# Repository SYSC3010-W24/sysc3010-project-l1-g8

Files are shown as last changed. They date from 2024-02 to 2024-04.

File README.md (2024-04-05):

# 🔥 FANS (Fire Alarm Notification System)

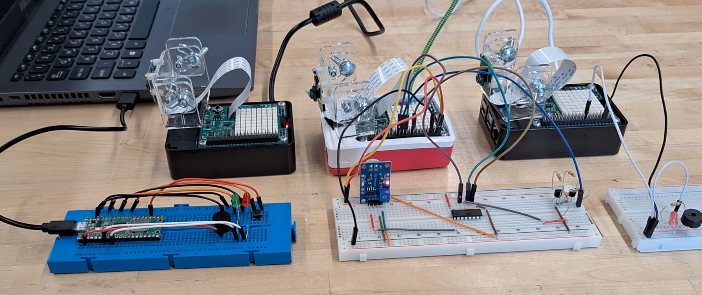
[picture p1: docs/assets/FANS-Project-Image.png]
Project Image


FANS is a comprehensive multi-system solution for fire-related emergencies that require prompt notification of persons
in the affected area.

FANS utilizes smoke and temperature sensors to accurately detect fires in its surrounding environment. Upon detection,
FANS issues SMS and email notifications to individuals in the surrounding area.

FANS provides a dashboard for live monitoring of its environment, as well as an interface for customizing things like
its sensitivity to pressure changes.

## Table Of Contents

- [Contributors](#contributors)  
- [Repository Organization](#repository-organization)
- [Installation and Setup Guide](#installation-and-setup-guide)
  - [Sensor Pi](#sensor-pi)
  - [Alarm System](#alarm-system)
  - [Notifier](#notifier)
  - [Pico Alarm](#pico-alarm)
  - [Web App](#web-app)

## Contributors

SYSC3010 group L1-G8, under guidance of TA Sean Kirkby.

- Grant Achuzia
- Javeria Sohail
- Matteo Golin
- Saja Fawagreh

## Repository Organization

FANS is composed of several different nodes. Within the project repository, each node is given its own directory
containing its required files.

- The data collection system is stored in [`sensor-pi/`][sensor-pi]
- The notification system is stored in [`notifier/`][notifier]
- The web GUI is stored in [`web-app/`][gui]
- The alarm system is stored in [`alarm-system/`][alarm]
- The haptic alarm system is stored in [`pico_alarm/`][haptic]

In addition, the `docs/` directory contains documentation on our system design. Within `docs/`, the `assets/` folder
contains all of the UML class, sequence, state machine and deployment diagrams which describe the FANS system and which
are used throughout our reports. The `design-report/` folder contains all of the LaTeX source files that compose the
FANS design report, and the `proposal/` folder contains the LaTeX source files for building our initial project proposal.

## Installation and Setup Guide

Guides to install and run each system node are provided below. Once all nodes have been set up, the system will be
functional.

- [Sensor Pi](#sensor-pi)
- [Alarm System](#alarm-system)
- [Notifier](#notifier)
- [Pico Alarm](#pico-alarm)
- [Web App](#web-app)

### Sensor-Pi

In order to set up the `sensor-pi` sensor data collection system, you will need:

- Raspberry Pi 4
- Sense hat
- Breadboard
- Wires
- 2x 10k resistors
- 2x 1k resistors
- 2x NPN bipolar-junction transistors
- Flying fish MQ2 smoke detector module

In order to assemble the circuit, place the components on your breadboard according to the following schematic. Power
sources can come from the Raspberry Pi or an external source. The labelled pin outputs (GPIO 22, SCLK, MOSI, MISO) are
all meant to be connected to the corresponding pin on the Raspberry Pi 4. Please see its [pinout][pi-pinout] sheet to
locate this pins.

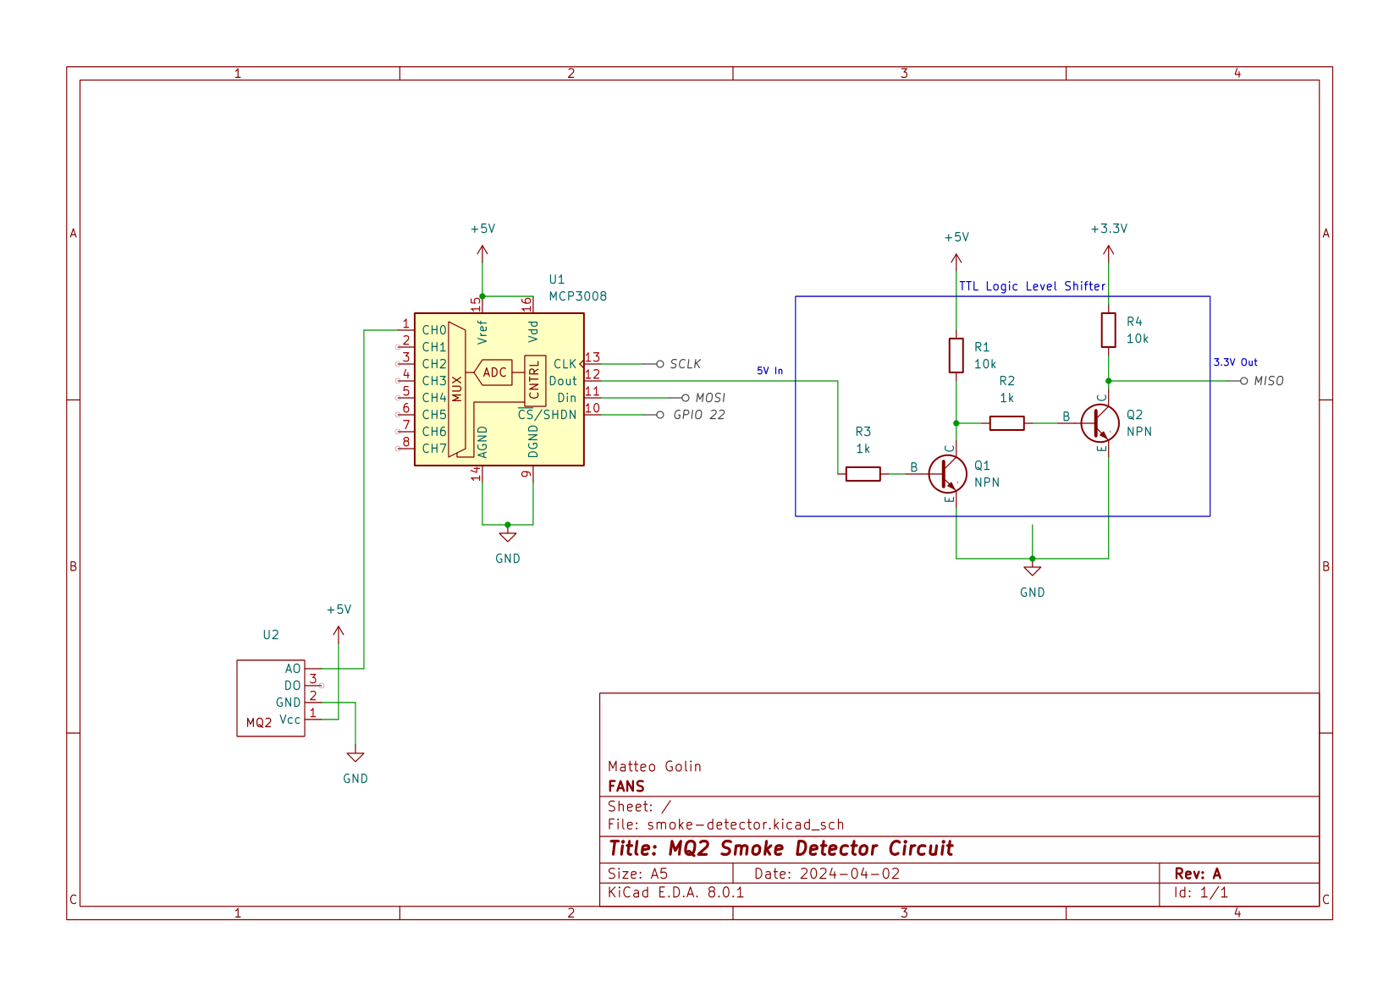
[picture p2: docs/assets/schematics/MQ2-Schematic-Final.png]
MQ2 smokedetector circuit


Ensure that the following files are present in the same directory for it to function properly:

- `firebase_config.json`: This file should include the configuration details required to connect to the Firebase
  database, such as the API key, authentication domain, database URL, and storage bucket.

Example `firebase_config.json` file:

```json
{
  "apiKey": "yourKey",
  "authDomain": "yourDomain",
  "databaseURL": "https://your-database-url",
  "storageBucket": "someStorageBucket"
}
```

Once the circuit is built and connected, the node can be started by running the software located in the `sensor-pi`
directory from the Raspberry Pi. Python 3.11 must be previously installed. The following commands will download the
repository and start the software when run in the terminal:

```console
git clone https://github.com/SYSC3010-W24/sysc3010-project-l1-g8.git
cd sysc-project-l1-g8/sensor-pi
python3 -m venv venv
source venv/bin/activate
pip install -r requirements.txt
python3 main.py
```

### Alarm System

In order to set up the `alarm-system` node, you will need:

- Raspberry Pi 4
- Breadboard
- Wires
- Passive piezoelectric buzzer
- Red LED
- 1k resistor

In order to assemble the circuit, place the components on your breadboard according to the following schematic. The 3.3V
input signal should be connected to the Raspberry Pi's GPIO 22 pin. Please see the Pi's [pinout][pi-pinout] sheet to
connect the pins properly.

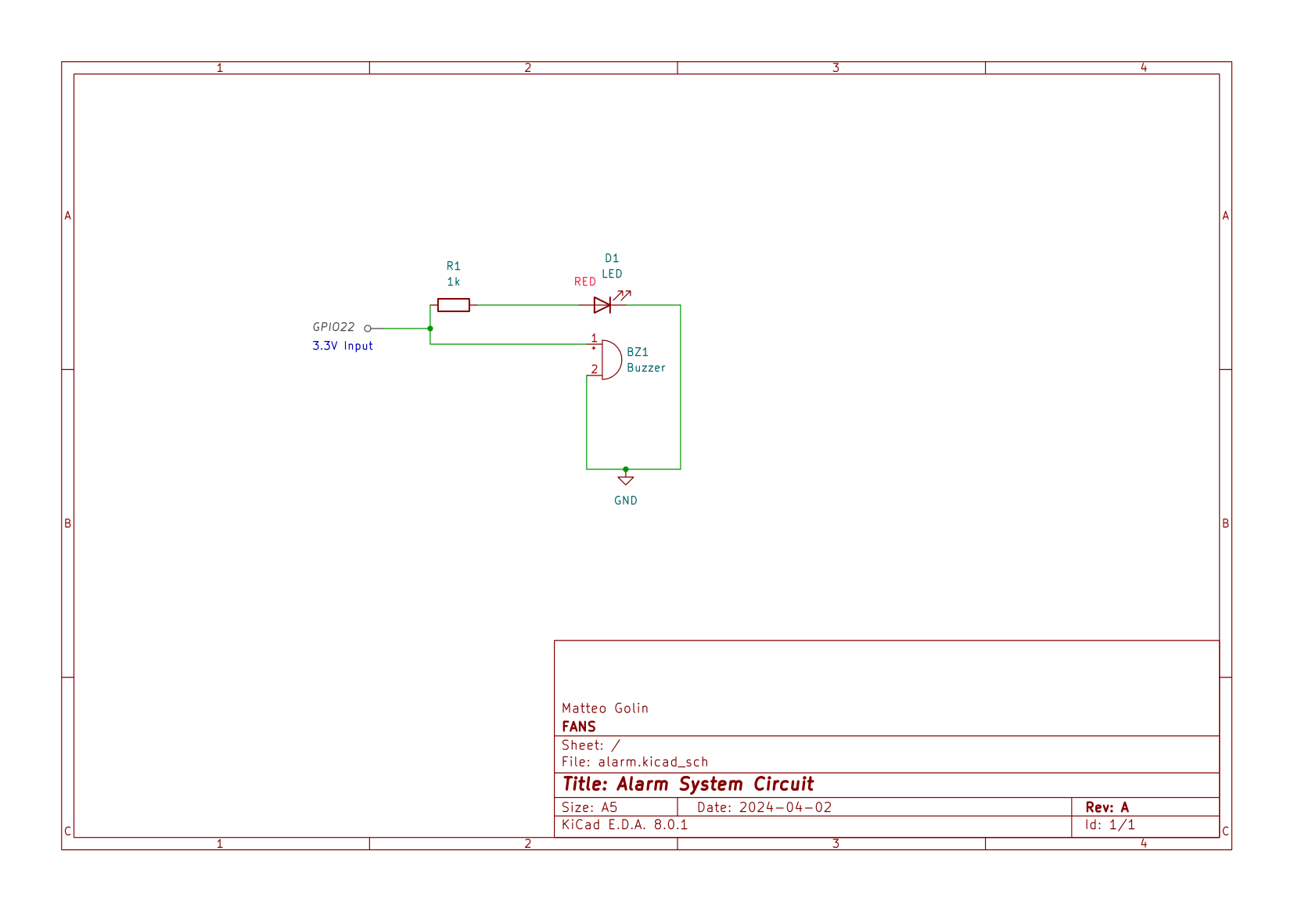
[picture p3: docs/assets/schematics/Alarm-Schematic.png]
Alarm system circuit


Once the circuit is assembled and connected, the node can be started by running the software located in the
`alarm-system` directory from the Raspberry Pi. Python 3.11 must be previously installed. The following commands will
download the repository and start the software when run in the terminal:

```console
git clone https://github.com/SYSC3010-W24/sysc3010-project-l1-g8.git
cd sysc-project-l1-g8/alarm-system
python3 -m venv venv
source venv/bin/activate
pip install -r requirements.txt
python3 main.py
```

### Notifier

In order to set up the `notifier` node, you will need:

- Raspberry Pi 4

The node can be started by running the software located in the notifier directory on the Raspberry Pi. Prior installation of Python 3.11 is required. Execute the following commands in the terminal to download the repository and start the software:

```console
git clone https://github.com/SYSC3010-W24/sysc3010-project-l1-g8.git
cd sysc-project-l1-g8/notifier
python3 -m venv venv
source venv/bin/activate
pip install -r requirements.txt
python3 email_notification_system.py
```

Additionally, ensure that the following files are present in the same directory for it to function properly:

- `fans_credentials.json`: This file should contain the username and password required for authentication to the email server, enabling the system to send notifications via email.
- `firebase_config.json`: This file should include the configuration details required to connect to the Firebase database, such as the API key, authentication domain, database URL, and storage bucket.
- `twilio_credentials.json`: This file should contain the authentication credentials for accessing the Twilio API, including the account SID and authentication token, enabling the system to send notifications via SMS.

### Pico-Alarm

In order to set up the `pico_alarm` buzzer alarm and led notifier system, you will need:

- Raspberry Pi Pico W
- Piezoelectric Buzzer
- 1 red and 1 green LED
- Breadboard
- Wires
- 2x 10k resistors

#### Hardware Assembly

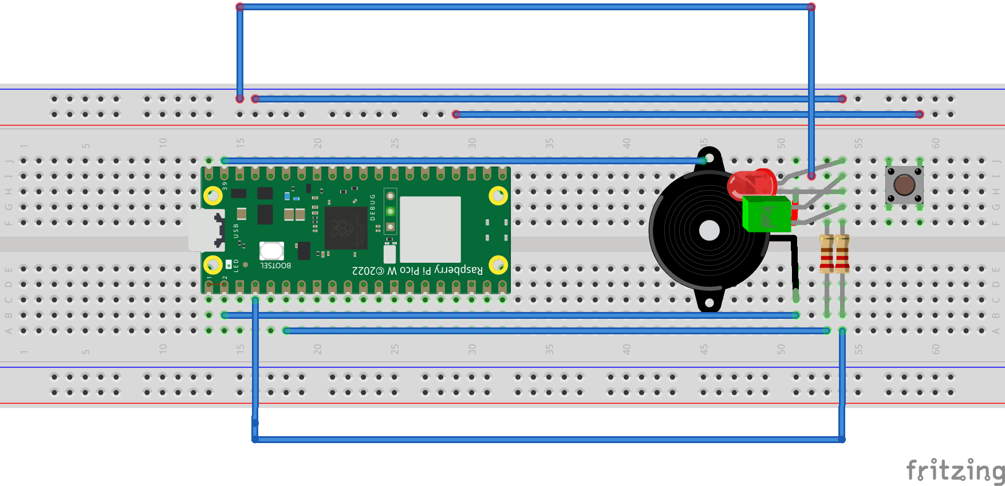
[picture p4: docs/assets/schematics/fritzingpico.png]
Fritzing schematic of pico alarm


1. **Connect the Buzzer** to GPIO 1 on the Pico W.
2. **Attach the Red LED** to GPIO 6 with a 10k resistor in series.
3. **Attach the Green LED** to GPIO 5 with a 10k resistor in series.
4. **Set up the Button** on GPIO 18, ensuring it's properly debounced with a 10k resistor.
5. **Wire everything** according to the schematic on a breadboard, ensuring secure connections.

#### Software Installation and Deployment for Pico_Alarm System

1. **Connect the Raspberry Pi Pico W** to your computer. Use a USB cable to establish the connection. Ensure the Pico is in MicroPython mode.
2. **Open Thonny IDE** on your computer. It's recommended to use Thonny for working with MicroPython on Raspberry Pi Pico due to its built-in support.
3. **Prepare the Python Script**: Have the `pico_alarm.py` script ready. This script includes the logic for monitoring the Firebase database and activating the buzzer and LEDs.
4. **Configure the Script**:
   - **WiFi Credentials**: Within the script, locate the `do_connect()` function. Replace `"your_wifi_ssid"` and `"your_wifi_password"` with your actual WiFi network SSID and password.
   - **Firebase URL**: Find the `firebase_url` variable in the script. Change its value to your Firebase database URL where the emergency flag will be checked.
5. **Deploy the Script to Pico W**:
   - In Thonny, select MicroPython (Raspberry Pi Pico) as the interpreter from the bottom right corner.
   - Open the `pico_alarm.py` script in Thonny.
   - Click on 'File' > 'Save As...' and choose to save the script on your Raspberry Pi Pico.
6. **Run the Script**:
   - With the `pico_alarm.py` script open in Thonny, press the green 'Run' button to execute the script on the Pico W.
   - The script will automatically start monitoring the Firebase database for any emergency flags and activate the buzzer and LEDs accordingly.

**Note**: The Raspberry Pi Pico W must be powered continuously for the alarm system to function. It can remain powered via the USB connection to your computer or through an external 5V power source.

#### Operational Notes

- The system checks the Firebase database at regular intervals for any emergency flags.
- The buzzer and red LED activate to indicate an emergency, with the green LED indicating normal operations.
- The button serves as an acknowledgment mechanism to stop the alarm and reset the system to its normal state.

[alarm]: https://github.com/SYSC3010-W24/sysc3010-project-l1-g8/tree/main/alarm-system
[sensor-pi]: https://github.com/SYSC3010-W24/sysc3010-project-l1-g8/tree/main/sensor-pi
[gui]: https://github.com/SYSC3010-W24/sysc3010-project-l1-g8/tree/main/web-app
[haptic]: https://github.com/SYSC3010-W24/sysc3010-project-l1-g8/tree/main/pico_alarm
[notifier]: https://github.com/SYSC3010-W24/sysc3010-project-l1-g8/tree/main/notifier
[pi-pinout]: https://www.the-diy-life.com/wp-content/uploads/2021/05/Raspberry-Pi-4-Pinout.png

### Web App

In order to set up the `web-app` node, you will need:

- Access to the internet

FANS web application is made using Flask, an easy to use Python micro framework. The `static/` folder contains css files for styling the app as well as a JS script for dynamically changing between themes. The `templates/` folder contains html files, and the `tests/` folder contains tests for making sure the application gets data from firebase.

Ensure that the following files are present in the same directory for it to function properly:

- firebase_config.json: This file should include the configuration details required to connect to the Firebase database, such as the API key, authentication domain, database URL, and storage bucket.
Example firebase_config.json file:

```python
{
  "apiKey": "yourKey",
  "authDomain": "yourDomain",
  "databaseURL": "https://your-database-url",
  "storageBucket": "someStorageBucket"
}
```

To gain access to the website, run the following commands in your terminal:

```console
git clone https://github.com/SYSC3010-W24/sysc3010-project-l1-g8.git
cd sysc-project-l1-g8/web-app
python3 -m venv venv
source venv/bin/activate
pip install -r requirements.txt
python3 main.py
```

In the terminal, click on the second http link to access the web app on a network server. Here's an example of what the second link may look like:  
`Running on http://192.168.X.X:5000/`

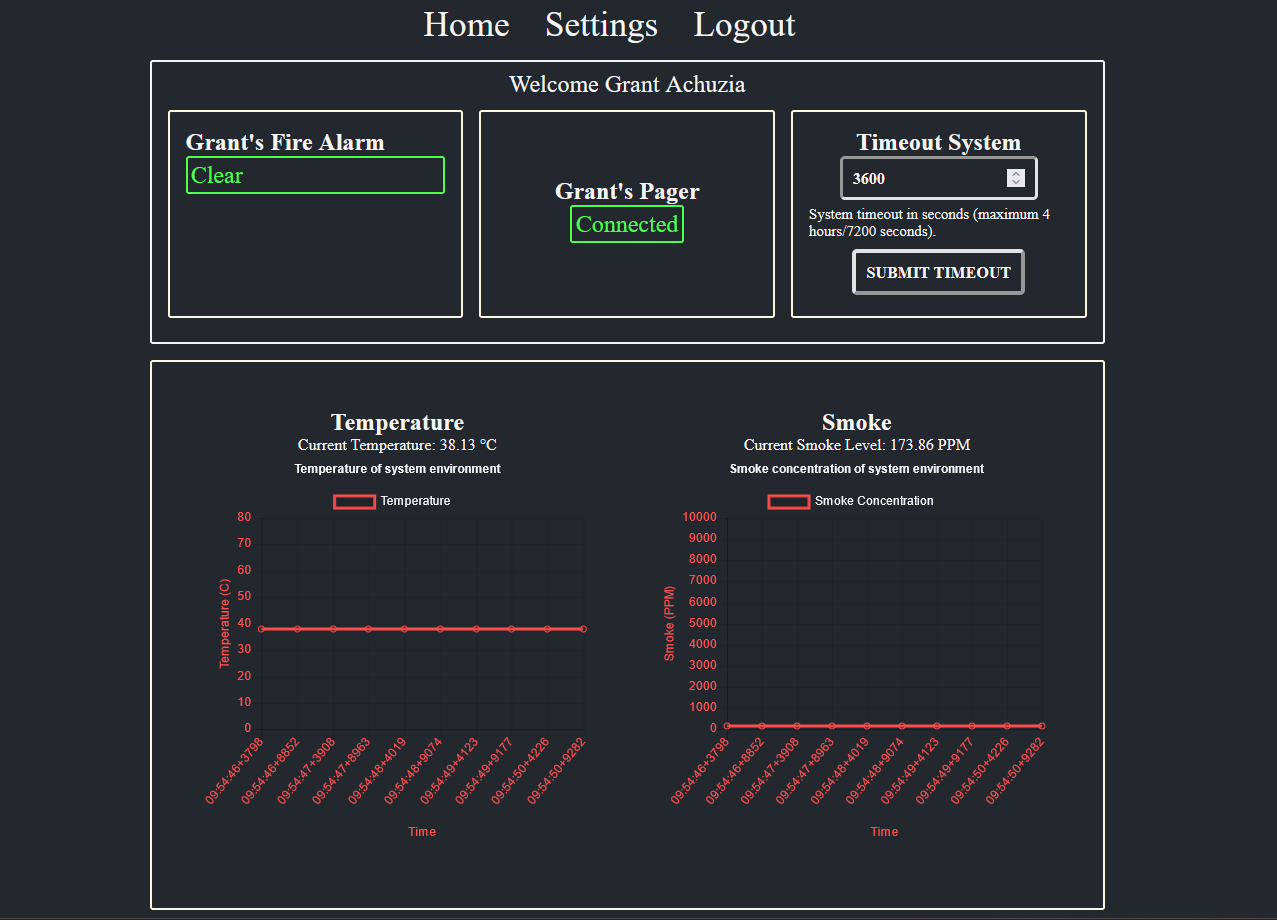
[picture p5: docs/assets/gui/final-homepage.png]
Web App home page image


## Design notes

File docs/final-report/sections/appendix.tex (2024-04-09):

\appendix

\pagebreak
\section{GitHub Repository README}

The following content is the README file taken from the FANS GitHub repository.

\def\pdffile{../../README.pdf}

\begin{center}
    

    

    

    

    

    

    

    
\end{center}

\section{Additional Use Cases} \label{ap:sequence}

The following sub-sections describe additional use cases that are handled by FANS, along with their sequence diagrams.

\subsubsection{Add New Contact Information Use Case}

The use case shown in Figure \ref{fig:add-contact} outlines the process of adding new contact information to the FANS
database. Through the web GUI, a user enters a new contact (name, email, phone, etc.) to be subscribed to emergency
notifications. Upon submission, these details are updated in the real-time cloud database. The notification system also
copies these changes to its local database a backup for possible connection loss.

\begin{figure}[H]
    \centering
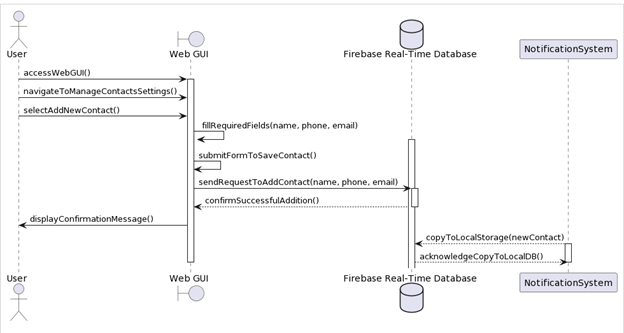
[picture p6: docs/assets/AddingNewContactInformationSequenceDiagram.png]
    
    \caption{The sequence diagram for the adding new contact information use case.}
    \label{fig:add-contact}
\end{figure}

\section{Schematics}

\begin{figure}[H]
    \centering
    
    \caption{The smoke detection system's electrical connections.}
\end{figure}

\begin{figure}[H]
    \centering
    
    \caption{The alarm system's electrical connections.}
\end{figure}

\begin{figure}[H]
    \centering
    
    \caption{The haptic alarm system's wiring diagram on a breadboard.}
\end{figure}

\section{State Machine Diagrams}

\subsection{Alarm System}

\begin{figure}[H]
    \centering
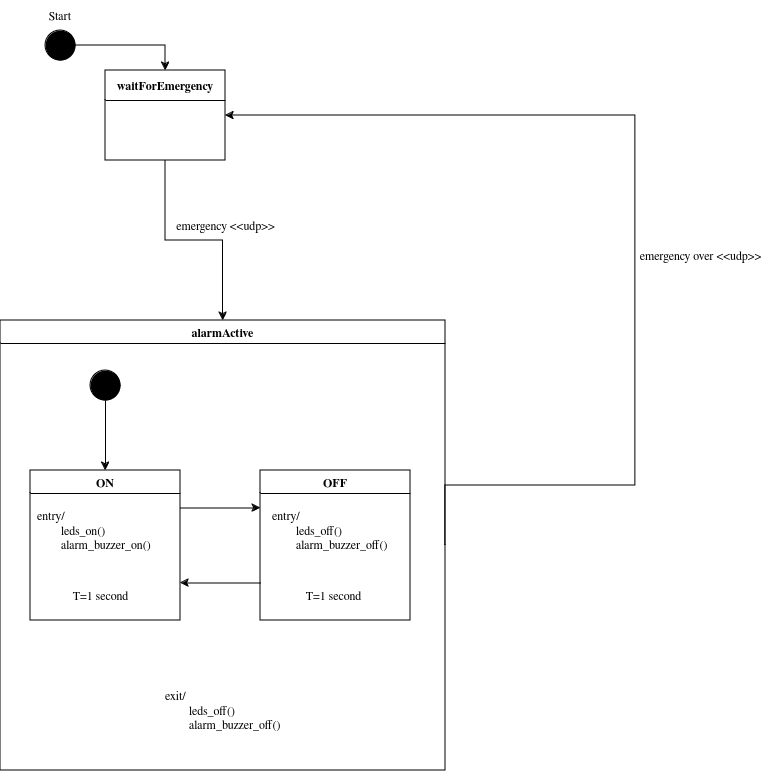
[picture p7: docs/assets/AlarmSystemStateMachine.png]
    
    \caption{The alarm system's software state machine.}
\end{figure}

\subsection{Smoke Detection System}

\begin{figure}[H]
    \centering
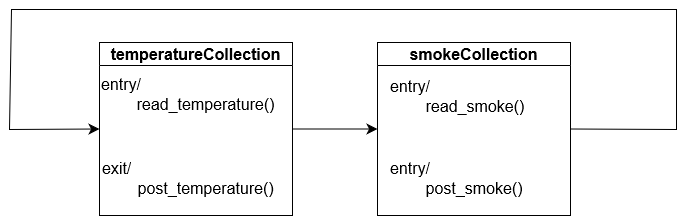
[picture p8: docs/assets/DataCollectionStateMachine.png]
    
    \caption{The smoke detection system's software state machine for data collection.}
\end{figure}

\begin{figure}[H]
    \centering
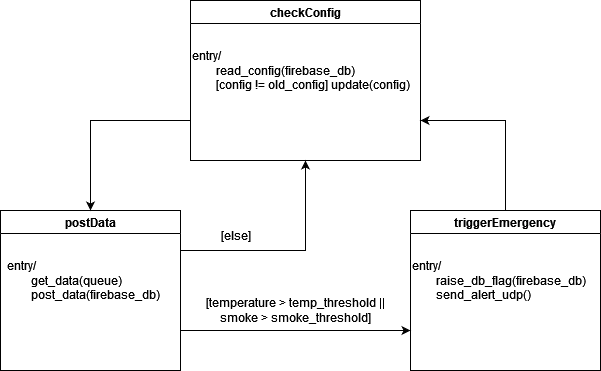
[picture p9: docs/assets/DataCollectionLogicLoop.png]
    
    \caption{The smoke detection system's software state machine for performing its primary logic.}
\end{figure}

\subsection{Notification System}

\begin{figure}[H]
    \centering
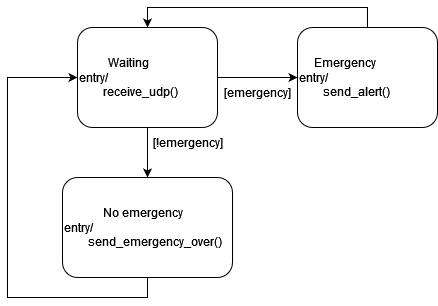
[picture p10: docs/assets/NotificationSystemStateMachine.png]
    
    \caption{The primary logic of the notification system as a state machine.}
\end{figure}

\subsection{Haptic Alarm}

\begin{figure}[H]
    \centering
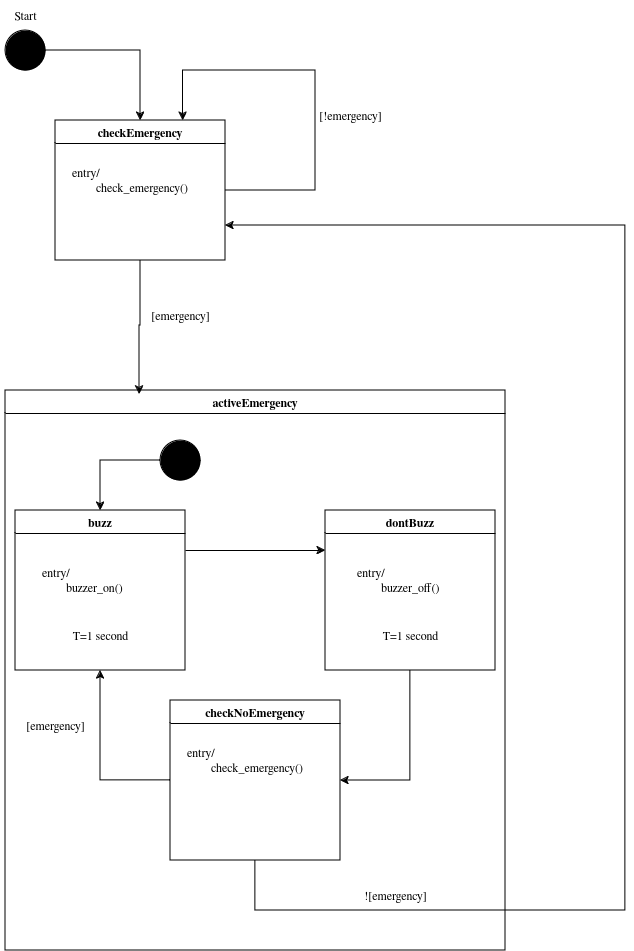
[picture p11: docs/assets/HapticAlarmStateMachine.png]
    
    \caption{The primary logic of the haptic alarm as a state machine.}
\end{figure}

\section{Class Diagrams}

\begin{figure}[H]
    \centering
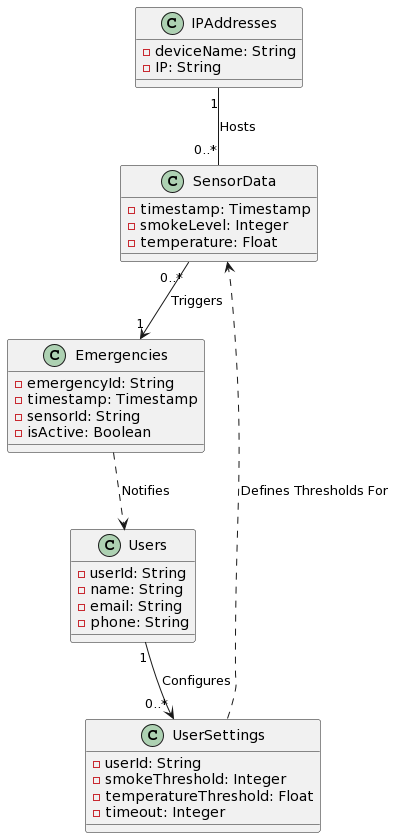
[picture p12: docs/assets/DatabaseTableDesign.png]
    
    \caption{Database table design.}
\end{figure}

\begin{figure}[H]
    \centering
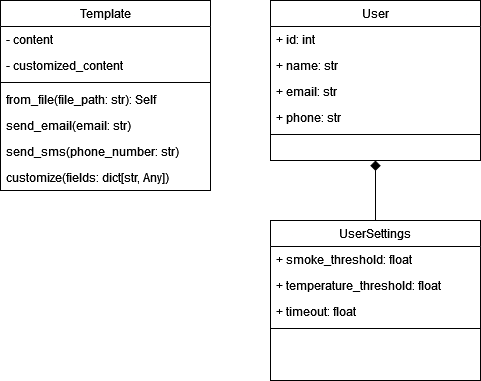
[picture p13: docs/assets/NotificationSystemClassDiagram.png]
    
    \caption{Class diagram of notification system.}
\end{figure}

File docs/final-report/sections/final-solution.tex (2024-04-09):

\section{Final Solution} \label{sec:final-solution}

The final solution for FANS is displayed in Figure \ref{fig:deployment}. This solution uses a distributed systems
approach to create a multi-node fire response system controlled via a web interface.

\subsection{Deployment Diagram}

The primary node in our FANS project is the sensor data collection node, which monitors temperature and smoke
concentration levels. All sensor measurements are written to the Firebase cloud database for display by the web UI.
When an emergency is detected, the sensor unit sends an alert over UDP and raises an emergency flag in the cloud
database.

The notification system and alarm system are subscribed to UDP messages sent by the sensor data collection node. This
allows them to be notified of detected emergencies even when they cannot read the emergency flag in the cloud database.

The haptic alarm and web UI are connect to the system through the cloud database. The haptic alarm activates its
emergency response when it sees a change in the emergency flag. The UI provides an interface for checking on the status
of an emergency and reviewing sensor data in real-time. Users can disable the emergency response from the UI when the
emergency has been resolved, and they can also time out the system’s emergency response whenever the system is falsely
triggered (smokey cooking). Finally, the UI also allows user contact information to be added to the subscriber list for
emergency notifications. All changes to settings from the UI are propagated through the cloud database to the sensor
unit and notification system over the internet.

\begin{figure}
    \centering
    
    \caption{The FANS deployment diagram.}
    \label{fig:deployment}
\end{figure}

\subsection{Message Protocol Table}

The system’s core, the Smoke Detection System, communicates with its temperature and smoke sensors using the I2C and
SPI protocols over the GPIO pins of a Raspberry Pi 4.

\subsubsection{I2C \& SPI Communication}

The Raspberry Pi 4 utilizes the I2C and SPI protocol to communicate with temperature and smoke sensors, monitoring
environmental conditions to detect potential fire hazards. These messages are outlined in \ref{table:i2c}.

\begin{table}
    \centering
    \footnotesize
    \begin{tabular}{| c | c | c | c | c |}
        \hline
        Sender         & Receiver               & Message              & Data Format                                          & Protocol                 \\
        \hline
        Raspberry Pi 4 & Temperature Sensor     & \texttt{read\_temp}  & See section 6.2.1 of datasheet \cite{temp-datasheet} & I2C                      \\
        \hline
        Raspberry Pi 4 & Smoke Sensor (via ADC) & \texttt{read\_smoke} & See figure 1.1 of datasheet \cite{adc-datasheet}     & SPI \cite{adc-datasheet} \\
        \hline
    \end{tabular}
    \caption{Messages for I2C communication in FANS.}
    \label{table:i2c}
\end{table}

\subsubsection{Local Area Network Communication}

Nodes within the FANS (smoke detection, alarm, and notification systems) communicate over a local network using UDP
packets, facilitating real-time alerts and system coordination. The messages sent over UDP use numerical value to
encode messages. The representation agreed upon is shown in Table \ref{table:udp-rep}. The messages sent are in Table
\ref{table:udp-messages}

\begin{table}
    \centering
    \footnotesize
    \begin{tabular}{| c | c |}
        \hline
        Message      & Value \\
        \hline
        Emergency    & 0     \\
        \hline
        No Emergency & 1     \\
        \hline
    \end{tabular}
    \caption{Numerical representation of messages over UDP in FANS.}
    \label{table:udp-rep}
\end{table}

\begin{table}
    \centering
    \footnotesize
    \begin{tabular}{| c | c | c | c | c |}
        \hline
        Sender                 & Receiver            & Message      & Data Format & Protocol \\
        \hline
        Smoke detection system & Notification system & Emergency    & 0           & UDP      \\
        \hline
        Smoke detection system & Alarm system        & Emergency    & 0           & UDP      \\
        \hline
        Smoke detection system & Notification system & No emergency & 1           & UDP      \\
        \hline
        Smoke detection system & Alarm system        & No Emergency & 1           & UDP      \\
        \hline
    \end{tabular}
    \caption{Messages for local area network communication in FANS.}
    \label{table:udp-messages}
\end{table}

\subsubsection{Cloud Database Communication}

Messages between each node and the Firebase database are shown in Table \ref{table:firebase}.

\begin{table}
    \centering
    \begin{tabular}{| c | c | c | c | c |}
        \hline
        Sender          & Receiver & Message                                    & Data Format                      & Protocol    \\
        \hline
        Smoke Detection & Cloud DB & \texttt{put\_sensor\_data()}               & See listing \ref{lst:sensor}     & HTTP (JSON) \\
        \hline
        GUI             & Cloud DB & \texttt{update\_threshold(new\_threshold)} & See listing \ref{lst:threshold}  & HTTP (JSON) \\
        \hline
        Notification    & Cloud DB & \texttt{query\_contact\_information()}     & See listing \ref{lst:contact}    & HTTP (JSON) \\
        \hline
        Haptic Alarm    & Cloud DB & \texttt{emergency()}                       & See listing \ref{lst:emergency}  & HTTP (JSON) \\
        \hline
        GUI             & Cloud DB & \texttt{get\_sensor\_data()}               & See listing \ref{lst:sensor-get} & HTTP (JSON) \\
        \hline
    \end{tabular}
    \caption{Messages for cloud database communication in FANS.}
    \label{table:firebase}
\end{table}

{
\tiny
\begin{lstlisting}[language=json,label={lst:sensor},caption={Update sensor data message.}]
{
  "method": "PUT",
  "path": "/sensor-data/temperature",
  "headers": {
    "Authorization": "Bearer YOUR_ACCESS_TOKEN",
    "Content-Type": "application/json"
  },
  "body": {
      "data": {
          "temperature": 21.2,
          "timestamp": "2024-03-13T08:37:22"
      }
  }
}
\end{lstlisting}

\begin{lstlisting}[language=json,label={lst:threshold},caption={Threshold update message.}]
{
  "method": "PUT",
  "path": "/system/threshold",
  "headers": {
    "Authorization": "Bearer YOUR_ACCESS_TOKEN",
    "Content-Type": "application/json"
  },
  "body": {
    "newThreshold": 50
  }
}
\end{lstlisting}

\begin{lstlisting}[language=json,label={lst:contact},caption={Request for user contact information.}]
{
  "method": "GET",
  "path": "/user/contact",
  "headers": {
    "Authorization": "Bearer YOUR_ACCESS_TOKEN"
  }
}
\end{lstlisting}

\begin{lstlisting}[language=json,label={lst:emergency},caption={Request for emergency flag.}]
{
  "method": "GET",
  "path": "/system/emergency",
  "headers": {
    "Authorization": "Bearer YOUR_ACCESS_TOKEN"
  }
}
\end{lstlisting}

\begin{lstlisting}[language=json,label={lst:sensor-get},caption={Request for latest sensor data.}]
{
  "method": "GET",
  "path": "/sensor-data",
  "headers": {
    "Authorization": "Bearer YOUR_ACCESS_TOKEN"
  }
}
\end{lstlisting}
}

\subsubsection{User Notification Communication}

The notification system communicates with users through email, employing standard internet protocols to ensure timely
and effective alerts.

\begin{table}[H]
    \centering
    \begin{tabular}{| c | c | c | c | c |}
        \hline
        Sender              & Receiver   & Message                & Data Format                 & Protocol     \\
        \hline
        Notification System & User Inbox & Emergency notification & See listing \ref{lst:email} & SMTP (Email) \\
        \hline
    \end{tabular}
    \caption{Messages for user notification communication in FANS.}
\end{table}

{
\tiny
\begin{lstlisting}[label={lst:email},caption={Email notification for detected emergency in FANS.}]
FROM: notification@example.com
TO: user@example.com
SUBJECT: Fire Alarm Notification

Dear [User's Name],

This is an emergency notification. Please exit the building.

Emergency detected: [Date, Time]

Stay safe!
\end{lstlisting}
}

\subsection{Sequence Diagrams}

The FANS system satisfies several core use cases. The three most critical use cases are shown below, and more detail
can be found in Appendix \ref{ap:sequence}.

\subsubsection{Trigger Emergency Use Case}

The trigger emergency use case shown in Figure \ref{fig:trigger-emerg} describes the critical functionality of FANS,
where the system detects a potential fire and initiates a series of automated responses to mitigate the situation. As
depicted in Figure \ref{fig:trigger-emerg}, the process begins when the smoke detection system identifies smoke and
potentially high temperatures indicative of a fire. This detection triggers a UDP notification to the alarm and
notification systems to alert them to begin their automated emergency responses. It additionally raises a flag in the
Firebase cloud database for non-local nodes (such as the haptic alarm) to begin their responses.

\begin{figure}
    \centering
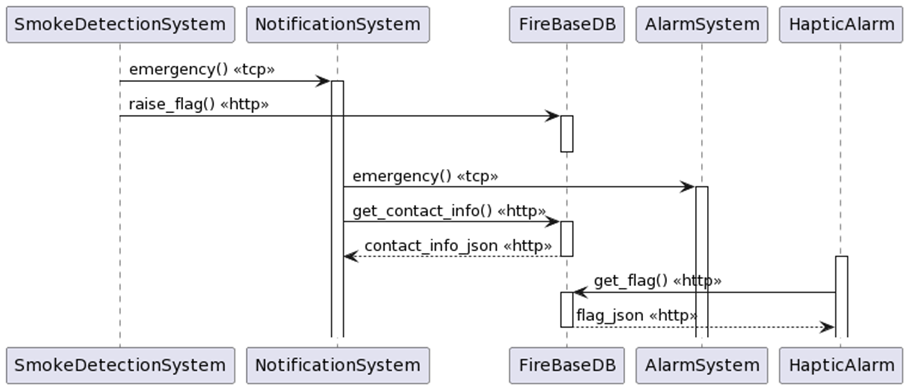
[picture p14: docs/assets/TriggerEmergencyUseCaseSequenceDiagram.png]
    
    \caption{The sequence diagram for the trigger emergency use case.}
    \label{fig:trigger-emerg}
\end{figure}

\subsubsection{Change Emergency Threshold Use Case}

Adjusting the smoke detection threshold is an essential feature that allows users to customize the sensitivity of the
FANS based on personal and environmental conditions. This use case, shown in Figure \ref{fig:change-thresh}, involves a
user accessing the web GUI to modify the threshold settings. Once the user submits their new thresholds, the web GUI
sends an update request to the database and displays a confirmation to the user. The smoke detector unit periodically
checks the thresholds in the database for updates, and updates its local values when it detects a change.

\begin{figure}
    \centering
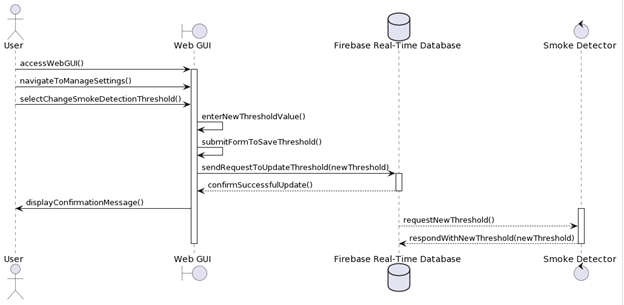
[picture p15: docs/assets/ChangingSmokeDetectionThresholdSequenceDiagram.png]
    
    \caption{The sequence diagram for the changing emergency threshold use case.}
    \label{fig:change-thresh}
\end{figure}

\subsubsection{Emergency Notification Use Case}

The scenario in Figure \ref{fig:emergency-resp} highlights FANS capability to notify users in the event of a detected
fire. Upon being notified of an emergency, the notification system queries the cloud database for contact information
and sends out alerts via SMS and email to all users. If the cloud database is not accessible, the local database is
instead used.

\begin{figure}
    \centering
    
    \caption{The sequence diagram for the emergency notification use case.}
    \label{fig:emergency-resp}
\end{figure}

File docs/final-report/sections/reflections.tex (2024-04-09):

\section{Reflections}

\subsection{Project Success}

Overall, the team considers our FANS to be a success. We were able to develop a comprehensive real-time system that
addresses the issues that arise with preventable fire-related deaths in Canada. FANS uses modern web technologies and
multiple communication protocols (I2C, UDP, and HTTP) to enhance its effectiveness.

FANS functions as we intended: detecting smoke and high temperatures, triggering multiple alarms, and sending prompt
notifications to registered users. The system's ability to detect potential fires and alert users in real-time is a
major part of the project’s success.

FANS sensors were reliable during testing. The system is easily expanded by simply running each distributed node on
more devices, which is a key use case for installing the system in larger buildings. Our GUI provides an intuitive
monitoring and control interface for users, allowing the user to check the emergency status, review the system's
environmental conditions, and manage alarm timeouts.

The FANS project can be considered a success due to its functionality, reliability, and scalability. It meets all of
the functional requirements originally laid out in the project proposal.

\subsection{Learning Experiences}

Developing FANS gave our team valuable experience and insight into creating a multi-faceted product.

One of the most significant learning experiences was gaining hands-on experience with the Raspberry Pi ecosystem.
Getting using the Raspberry Pi's terminal, learning MicroPython for the Pico, and applying our electronics knowledge to
build circuits connected to microcontrollers were all essential to the growth of our technical ability.

Our time-management skills were also strengthened, as we learned to write our reports alongside development to keep
records of our progress and design evolution. Communication amongst the team was critical, and we learned to leverage
our varying skill sets across different aspects of the project. We resolved conflicts (scheduling and opinion-based)
constructively while working together to meet all our milestones.

\subsection{Project Extensions}

The inclusion of geographically aware system nodes would make FANS a more robust system. Making FANS nodes
geographically aware would allow the emergency response to only target affected users. In addition, haptic alarm
buzzers would only buzz if the wearer is within a certain range of the affected area. Only users within the affected
area should be notified via email and SMS to steer clear of the area. Using geographic location information, FANS could
be modified to subscribe users to emergency response measures only if they are within the affected area, making it more
effective.

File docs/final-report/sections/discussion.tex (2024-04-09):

\section{Discussion of Final Design}

Although our team adhered to the specifications and objectives originally outlined in our proposal, we did make some
modifications to our original plan as we learned more and got further into our project.

\textbf{Changes Made}

The first change that was made to FANS from the original specification was the LCD screen component. We had originally
planned to add a monitor to the smoke detection unit, but realized during development that it would not have a
practical use since the unit would likely be ceiling mounted where the monitor is not visible.

The second change to our original proposal, which was made several times, was our project timeline. As we developed our
system we realized that our time estimates were not completely accurate. We adjusted our timeline several times to
allocate more resources to development of more difficult portions. For instance, we had to order new components after
the component request period in order to properly interface with our smoke sensor. This caused us to push back the
smoke detection portion of the system until the components arrived.

\textbf{Findings}

The smoke detection unit for our system was not entirely accurate due to electrical noise and some calibration
requirements that could not be met. The data sheet advised to measure air resistance of smoke, but we could not find
any fully reliable values for this online. We simply tuned the sensor to not trigger it's onboard LED in the absence of
smoke. Our system reports a very small PPM measurement of smoke in clear environments due to the calibration issues and
the electrical noise of our breadboard (likely due to the home-made logic level converter).

The temperature sensor was reliable and could accurately detect temperature changes, but had a baseline of around 38
degrees Celsius due to the heat from the CPU accumulating inside the Pi case. Removing the case or mounting the sensor
further away from the CPU could help reduce this.

During our testing, we determined that from moment the smoke detection unit triggered an emergency, the response from
all nodes in the system (alarms, lights, web UI) took a maximum of one second. This is likely dependent on the network
speed, but our system's UDP messages are deliberately short for maximum transmission speed. The longest response time
was for email notifications due to latency in the mail carrier outside of our control, but the notification system and
other local nodes responded to the emergency trigger in under a second.

Scalability was also confirmed by doubling up on specific nodes during testing. We would convert our team's Pis to be
two sensor nodes or two alarm nodes. Since our messages are sent over UDP and internet in a way that can be consumed by
multiple listeners, all of our system nodes could be present in any number without any changes to the system's logic.

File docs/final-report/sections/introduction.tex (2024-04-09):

\section{Project Description}

\subsection{Motivation}

The motivation for the FANS project was to address the critical problem of preventable fire-related deaths in Canada.
By leveraging modern technological advancements, the FANS system aimed to significantly enhance the effectiveness of
fire alarm systems, reducing response times, and ultimately saving lives. The importance of this project could not be
overstated, as it directly impacts the well-being of Canadians.

\subsection{Problem Statement}

The Fire Alarm Notification System (FANS) was created to address the alarming number of preventable fire deaths in
Canada. There are 220 annual fire-related casualties, and at least one in seven of these deaths occurs in a home
without working smoke alarms \cite{fire-stats}. This emphasizes the shortcomings of traditional fire alarm systems,
which often lacked advanced communication capabilities and robust monitoring capabilities \cite{modern-fire-alarms}.

The FANS project addresses these issues by integrating smoke and temperature sensors with Internet of Things (IoT)
technology. This approach not only covers scenarios where smoke may not reach the detecting device but also offers
real-time notifications via SMS and email, thus notifying homeowners immediately in the event of an emergency.

With configurable thresholds for smoke and temperature alarms and adjustable timeouts that prevent the system from
being unsafely disabled, FANS uses technological advances to significantly improve the effectiveness of fire detection
systems. The ultimate goal of the project is to improve overall fire safety and emergency response, and thereby
mitigate fire disasters and protect the well-being of individuals, families, and communities across Canada
\cite{smoke-alarm-gc}.

\subsection{Overview of Solution}

The FANS system is comprised of several key components in a distributed system for greater efficacy of emergency
detection. The system's architecture is outlined in section \ref{sec:final-solution}.

Our smoke detection system continuously monitors the environment for smoke and temperature changes using different
digital and analog sensors. It serves as the detection mechanism for emergencies, and is responsible for activating the
system's emergency response when abnormal measurements are detected. Emergency activation is done both over local
network communication to other nodes, and over the internet to nodes that may be connected to different networks. This
creates a redundancy for inter-node communication, which can be critical in case of internet connection loss during an
emergency.

The alarm system triggers loud audible and visual alerts in the event of a fire, ensuring occupants are immediately
warned in emergency situations. It can be stationed in high traffic areas for maximum efficacy.

The FANS notification system immediately sends out emergency alerts over email and SMS to a predefined contact list of
users, ensuring rapid response to the detected fire. The system maintains a local database copy of the cloud database
to ensure that these critical messages are still sent if connection to the cloud service is lost.

Finally, FANS utilized a Pi Pico wearable device to provide immediate feedback to individual users, offering an
additional layer of alert through a loud wearable alarm and blinking LEDs for visuals. This is best suited to
individuals with hearing impairments or who may not always be within a close distance to the alarm system nodes.

The entire system can be controlled from a web GUI, where a system administrator can subscribe more contacts to
emergency notifications, modify detection thresholds, timeout the system and watch real-time visualizations of smoke
and temperature measurements being taken.

Our design enables easy expansion with additional sensor or alarm units as needed. Each component functions
independently and has multiple redundancies for inter-node communication, ensuring reliability and ease of maintenance.

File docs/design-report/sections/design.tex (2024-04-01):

\section{Design Overview}

The Fire Alarm Notification System (FANS) is a real-time system designed for efficient fire detection and alerting. The
system is composed of several key components, each with a distinct function but integrated to work seamlessly together,
ensuring a comprehensive approach to fire safety. The system's architecture is outlined in a detailed deployment
diagram in Figure \ref{fig:deployment}, illustrating the interconnections between the various components. These
components include:

\begin{itemize}
    \item \textbf{Alarm System:} Based on a Raspberry Pi 4, this system triggers audible and visual alerts in the event
          of a fire, ensuring that occupants are promptly warned.

    \item \textbf{Smoke Detection System:} Also utilizing a Raspberry Pi 4, this system constantly monitors the
          environment for smoke using advanced sensors. It is the primary detection mechanism that activates the alarm
          system and notification system upon detecting smoke.

    \item \textbf{Notification System:} Operating on a Raspberry Pi 4, this system sends out emergency alerts to
          predefined contacts, including both local authorities and individuals, ensuring rapid response to the detected
          fire.

    \item \textbf{Cloud Database:} A real-time cloud database is employed to store critical data, including sensor
          readings (smoke and temperature levels) and system configurations. This facilitates remote monitoring and
          configuration, ensuring that the system is always functioning optimally.

    \item \textbf{Haptic Alarm:} This device provides haptic feedback, offering an additional layer of alert through
          physical sensation, ensuring that even those who may not be within hearing range of the alarm or have hearing
          impairments are alerted.

    \item \textbf{User Interface:} A web-based application for monitoring the system's environment and configuring
          system settings.
\end{itemize}

The system's design emphasizes scalability, allowing for easy expansion with additional sensors or alarm units as
needed. It also highlights modularity, where each component can function independently, ensuring reliability and ease
of maintenance. Communication between the components is facilitated through a local network, with the cloud database
supporting remote access and control.

Furthermore, the system incorporates advanced communication protocols for efficient data exchange and alerting. The
smoke detection system employs the I2C protocol for sensor communication, while UDP packets facilitate local network
communication between the system's nodes. HTTP requests are utilized for interactions with the cloud-hosted real-time
Firebase database, ensuring timely updates and access to system data.

Overall, the Fire Alarm Notification System is designed to be a reliable, efficient, and scalable solution for fire
detection and notification, leveraging modern technology to provide real-time alerts and ensuring the safety of
occupants in any building.

\subsection{System Overview Design}

\begin{figure}[H]
    \centering
    
    \caption{The deployment diagram for FANS.}
    \label{fig:deployment}
\end{figure}

\subsection{Communication Protocols}

In the Fire Alarm Notification System (FANS), a variety of communication protocols are meticulously integrated to
ensure seamless interaction among the system components and with the external cloud database, facilitating a robust and
responsive fire alarm solution.

The system's core, the Smoke Detection System, communicates with its temperature and smoke sensors using the I2C
protocol over the GPIO pins of a Raspberry Pi 4. This protocol choice is pivotal for real-time data acquisition,
allowing the system to monitor environmental conditions continuously and detect any signs of fire immediately. For
interactions within the local network, including communication between the smoke detection system, the alarm system,
and the notification system, UDP packets are employed. This approach is selected for its efficiency and speed, ensuring
that critical data is transmitted quickly and reliably across the system components without the overhead of
establishing and maintaining a connection, which is crucial in emergency situations where every second counts.

The integration with the cloud is achieved through HTTP requests to a Firebase real-time database. This cloud database
is essential for storing sensor data, system configurations, and user information. It supports various operations,
including the posting of sensor data by the smoke detection system, retrieval of data for the web GUI, fetching contact
information for the notification system, and polling for emergency flags by the haptic alarm system. These interactions
are facilitated by HTTP's flexibility and its widespread support across internet infrastructure, enabling the FANS to
leverage cloud computing benefits for enhanced data management and accessibility.

Lastly, the notification system's ability to reach users through email and SMS text notifications is realized through
standard internet SMS and email protocols. This ensures that in the event of a fire, users are promptly informed
regardless of their location, providing critical information and instructions to enhance their safety and response
effectiveness.

Together, these communication protocols form the backbone of the Fire Alarm Notification System, enabling it to
function as a cohesive, efficient, and highly responsive fire safety solution.

The Fire Alarm Notification System (FANS) employs a variety of communication protocols to ensure seamless interactions
between its components and with the external cloud database. This section provides detailed tables describing each
communication pathway.

\subsubsection{I2C Communication}

The Raspberry Pi 4 utilizes the I2C protocol to communicate with an array of temperature and smoke sensors, monitoring
environmental conditions to detect potential fire hazards. This is not visible in the sequence diagrams as they show
the bigger picture of the communication of the nodes with the sensors.

\begin{table}[H]
    \centering
    \begin{tabular}{| c | c | c | c | c |}
        \hline
        Sender         & Receiver               & Message              & Data Format                                          & Protocol                 \\
        \hline
        Raspberry Pi 4 & Temperature Sensor     & \texttt{read\_temp}  & See section 6.2.1 of datasheet \cite{temp-datasheet} & I2C                      \\
        \hline
        Raspberry Pi 4 & Smoke Sensor (via ADC) & \texttt{read\_smoke} & See figure 1.1 of datasheet \cite{adc-datasheet}     & SPI \cite{adc-datasheet} \\
        \hline
    \end{tabular}
    \caption{Messages for I2C communication in FANS.}
\end{table}

\subsubsection{Local Area Network Communication}

Nodes within the FANS (smoke detection, alarm, and notification systems) communicate over a local network using UDP
packets, facilitating real-time alerts and system coordination.

The messages sent over UDP use numerical value to encode messages. The representation agreed upon is as follows:

\begin{table}[H]
    \centering
    \begin{tabular}{| c | c |}
        \hline
        Message      & Value \\
        \hline
        Emergency    & 0     \\
        \hline
        No Emergency & 1     \\
        \hline
    \end{tabular}
    \caption{Numerical representation of messages over UDP in FANS.}
\end{table}

\begin{table}[H]
    \centering
    \begin{tabular}{| c | c | c | c | c |}
        \hline
        Sender                 & Receiver            & Message      & Data Format & Protocol \\
        \hline
        Smoke detection system & Notification system & Emergency    & 0           & UDP      \\
        \hline
        Smoke detection system & Alarm system        & Emergency    & 0           & UDP      \\
        \hline
        Smoke detection system & Notification system & No emergency & 1           & UDP      \\
        \hline
        Smoke detection system & Alarm system        & No Emergency & 1           & UDP      \\
        \hline
    \end{tabular}
    \caption{Messages for local area network communication in FANS.}
\end{table}

\subsubsection{Cloud Database Communication}

\begin{table}[H]
    \centering
    \begin{tabular}{| c | c | c | c | c |}
        \hline
        Sender          & Receiver & Message                                    & Data Format                      & Protocol    \\
        \hline
        Smoke Detection & Cloud DB & \texttt{put\_sensor\_data()}               & See listing \ref{lst:sensor}     & HTTP (JSON) \\
        \hline
        GUI             & Cloud DB & \texttt{update\_threshold(new\_threshold)} & See listing \ref{lst:threshold}  & HTTP (JSON) \\
        \hline
        Notification    & Cloud DB & \texttt{query\_contact\_information()}     & See listing \ref{lst:contact}    & HTTP (JSON) \\
        \hline
        Haptic Alarm    & Cloud DB & \texttt{emergency()}                       & See listing \ref{lst:emergency}  & HTTP (JSON) \\
        \hline
        GUI             & Cloud DB & \texttt{get\_sensor\_data()}               & See listing \ref{lst:sensor-get} & HTTP (JSON) \\
        \hline
    \end{tabular}
    \caption{Messages for cloud database communication in FANS.}
\end{table}

\begin{lstlisting}[language=json,label={lst:sensor},caption={Update sensor data message.}]
{
  "method": "PUT",
  "path": "/sensor-data/temperature",
  "headers": {
    "Authorization": "Bearer YOUR_ACCESS_TOKEN",
    "Content-Type": "application/json"
  },
  "body": {
      "data": {
          "temperature": 21.2,
          "timestamp": "2024-03-13T08:37:22"
      }
  }
}
\end{lstlisting}

\begin{lstlisting}[language=json,label={lst:threshold},caption={Threshold update message.}]
{
  "method": "PUT",
  "path": "/system/threshold",
  "headers": {
    "Authorization": "Bearer YOUR_ACCESS_TOKEN",
    "Content-Type": "application/json"
  },
  "body": {
    "newThreshold": 50
  }
}
\end{lstlisting}

\begin{lstlisting}[language=json,label={lst:contact},caption={Request for user contact information.}]
{
  "method": "GET",
  "path": "/user/contact",
  "headers": {
    "Authorization": "Bearer YOUR_ACCESS_TOKEN"
  }
}
\end{lstlisting}

\begin{lstlisting}[language=json,label={lst:emergency},caption={Request for emergency flag.}]
{
  "method": "GET",
  "path": "/system/emergency",
  "headers": {
    "Authorization": "Bearer YOUR_ACCESS_TOKEN"
  }
}
\end{lstlisting}

\begin{lstlisting}[language=json,label={lst:sensor-get},caption={Request for latest sensor data.}]
{
  "method": "GET",
  "path": "/sensor-data",
  "headers": {
    "Authorization": "Bearer YOUR_ACCESS_TOKEN"
  }
}
\end{lstlisting}

\subsubsection{User Notification Communication}

The notification system communicates with users through email, employing standard internet protocols to ensure timely
and effective alerts.

\begin{table}[H]
    \centering
    \begin{tabular}{| c | c | c | c | c |}
        \hline
        Sender              & Receiver   & Message                & Data Format                 & Protocol     \\
        \hline
        Notification System & User Inbox & Emergency notification & See listing \ref{lst:email} & SMTP (Email) \\
        \hline
    \end{tabular}
    \caption{Messages for user notification communication in FANS.}
\end{table}

\begin{lstlisting}[label={lst:email},caption={Email notification for detected emergency in FANS.}]
FROM: notification@example.com
TO: user@example.com
SUBJECT: Fire Alarm Notification

Dear [User's Name],

Fire alarm detected. Evacuate immediately.

- Location: [Location]
- Date/Time: [Date/Time]

Stay safe!
\end{lstlisting}

\subsection{Message Sequence Diagrams}

To implement the functional requirements described in Section 1.1: Functional Requirements, the FANS system will
satisfy six core use cases highlighted and illustrated in the message sequence diagrams below.

\subsubsection{Trigger Emergency Use Case}

The Trigger Emergency Use Case represents the critical functionality of the FANS, where the system detects a potential
fire through its smoke detection system and initiates a series of automated responses to mitigate the situation. As
depicted in the message sequence diagram, the process begins when the smoke detection system identifies smoke and
potentially high temperatures indicative of a fire. This detection triggers the system to send a notification to the
alarm system and the notification system. The alarm system responds by sounding an audible and visible alert to notify
occupants of the building immediately. Concurrently, the notification system sends out emergency alerts via SMS and
email to all registered users, ensuring they are informed of the danger regardless of their current location. This
response ensures that all the users are promptly alerted to the emergency, resulting in a quick evacuation and response
to the detected threat.

\begin{figure}[H]
    \centering
    
    \caption{Sequence diagram for the trigger emergency use case.}
\end{figure}

\subsubsection{Add New Contact Information Use Case}

This use case outlines the process by which users can add new contact information to the FANS database. Through the web
GUI, a user enters new contact details, such as phone numbers and email addresses, that the system can use to send
emergency notifications. Upon submission, these details are updated in the real-time database. The message sequence
diagram for this use case (not shown) illustrates the interactions between the user, the web GUI, and the database,
culminating in the notification system being updated with the new contact information. This ensures that the FANS can
reach the user through various channels in the event of an emergency, enhancing the system's effectiveness in
communicating critical alerts.

\begin{figure}[H]
    \centering
    
    \caption{Sequence diagram for the add contact info use case.}
\end{figure}

\subsubsection{Change Emergency Threshold Use Case}

Adjusting the smoke detection threshold is an essential feature that allows users to customize the sensitivity of the
FANS based on environmental conditions and personal preferences. This use case involves a user accessing the web GUI to
modify the threshold settings that determine when the smoke detection system should trigger an alert. The message
sequence diagram (not shown) visualizes the steps involved, from the user's interaction with the GUI to update the
threshold to the real-time database's role in storing this new setting. The smoke detection system then retrieves and
applies the updated threshold, ensuring that the FANS operates according to the user's specifications, balancing
sensitivity and false alarm minimization.

\begin{figure}[H]
    \centering
    
    \caption{Sequence diagram for the change threshold use case.}
\end{figure}

\subsubsection{Emergency Response Use Case}

This scenario highlights the FANS's capability to notify users in the event of a detected fire. Upon detecting a fire,
the notification system queries the cloud database for contact information and then sends out alerts via SMS and email
to all users. The message sequence diagram for this use case (provided above) captures the sequence of these
interactions, showcasing how the system ensures that occupants are informed and ready to address the emergency
promptly.

\begin{figure}[H]
    \centering
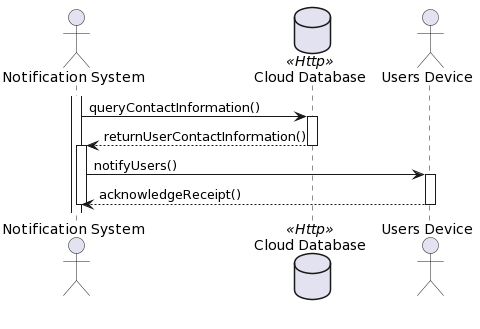
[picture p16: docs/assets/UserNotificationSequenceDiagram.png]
    
    \caption{Sequence diagram for the emergency response use case.}
\end{figure}

\subsection{Database Table Schema}

The FANS project will employ a Firebase Real-Time Database to store and manage data crucial for its operation. Given
the real-time nature of the FANS system, the choice of Firebase facilitates immediate updates and retrieval of data,
which is vital for emergency detection and notification. The data structure is designed to ensure efficient data
storage, retrieval, and management while supporting the scalability and real-time data processing requirements of the
system.

\begin{figure}[H]
    \centering
    
    \caption{A visual of the FANS database design schema.}
\end{figure}

This schema optimizes the FANS system's performance by enabling efficient data storage, quick access to historical
data, and seamless integration between the system's components. The design also supports scalability, allowing for easy
addition of new sensors and users without significant alterations to the underlying database structure.

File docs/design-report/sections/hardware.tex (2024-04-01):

\section{Hardware Design}

FANS is composed of various hardware components to perform its desired functionality.

\subsection{Raspberry Pi SenseHat}

The Raspberry Pi SenseHat is responsible for providing the temperature data readings collected by the smoke detection
system. This component was chosen because it's readily available and also has a large number of tutorials available for
integrating it into systems \cite{sensehat}. A diagram is not shown as the SenseHat is self-contained and can simply be
directly place on top of the Raspberry Pi 4, connected via the GPIO pin headers.

\subsection{MQ2 Smoke Sensor}

The MQ2 Smoke Sensor is a critical component in the FANS project, chosen for its capability to detect a wide range of
gases that occur, including smoke, which is essential for early fire detection. It operates at 5V and outputs an analog
signal that varies with the concentration of detected gases. The sensor's sensitivity to smoke enables the system to
promptly identify fire hazards, triggering alerts and activating safety measures. Its analog output necessitates an
analog-to-digital converter (ADC) when used with a Raspberry Pi, ensuring accurate detection levels are communicated to
the system for processing and response.

\begin{figure}[H]
    \centering
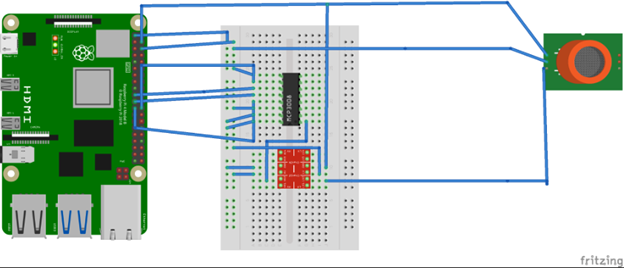
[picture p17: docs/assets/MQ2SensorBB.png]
    
    \caption{Bread board configuration of the smoke sensor.}
\end{figure}

\begin{figure}[H]
    \centering
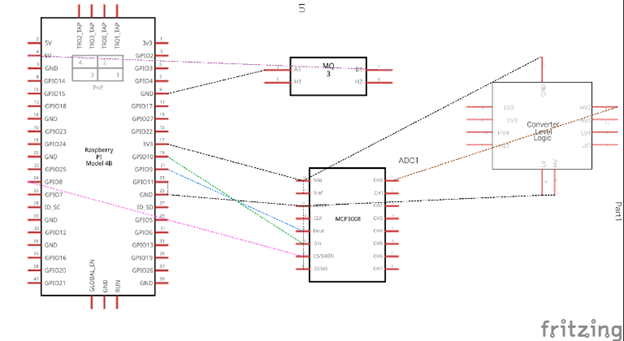
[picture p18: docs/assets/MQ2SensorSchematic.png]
    
    \caption{Schematic of the smoke sensor circuit.}
\end{figure}

\subsection{LCD Display}

The project incorporates a 16x2 character LCD Display for real-time monitoring, utilizing the I2C communication
protocol for easy interfacing with the Raspberry Pi . This display operates on either 5V or 3.3V and is used to flash
in an emergency to indicate as smoke levels and temperature rise directly to the user. The choice of an LCD display
ensures that information about the environmental condition is immediately accessible, providing a quick overview
without needing to access the system digitally.

\begin{figure}[H]
    \centering
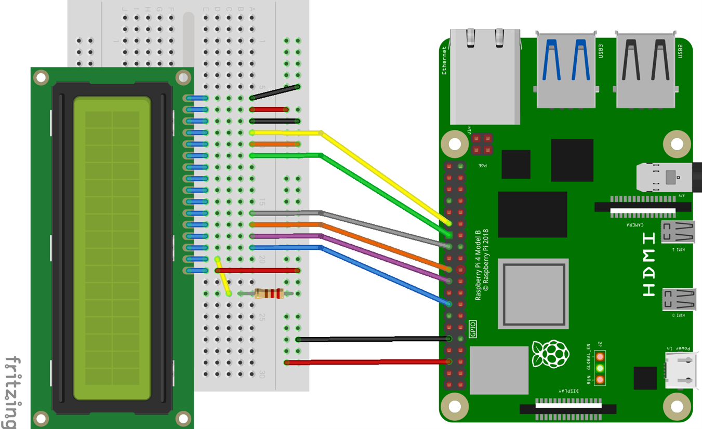
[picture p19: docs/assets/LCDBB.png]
    
    \caption{Bread board configuration of the LCD display.}
\end{figure}

\begin{figure}[H]
    \centering
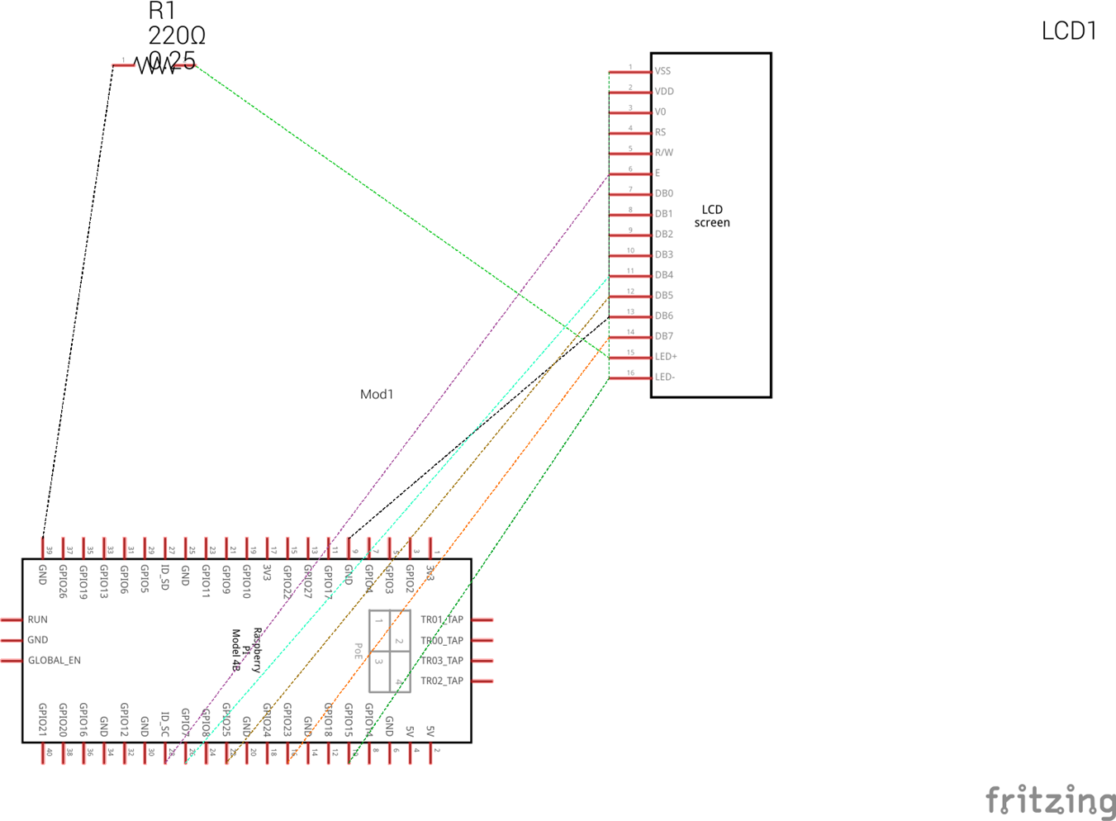
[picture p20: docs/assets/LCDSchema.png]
    
    \caption{Schematic of the LCD display circuit.}
\end{figure}

\subsection{Piezoelectric Buzzer}

The inclusion of a simple piezoelectric buzzer in the system design offers an effective way to generate audible alerts
when smoke or high temperatures are detected. Operating between 3.3V to 5V and controlled via a GPIO pin, the buzzer
can produce a range of tones, making it a versatile component for different alert types. It ensures that the system can
attract attention through sound, complementing visual alerts and enhancing the overall effectiveness of the fire
detection system.

\begin{figure}[H]
    \centering
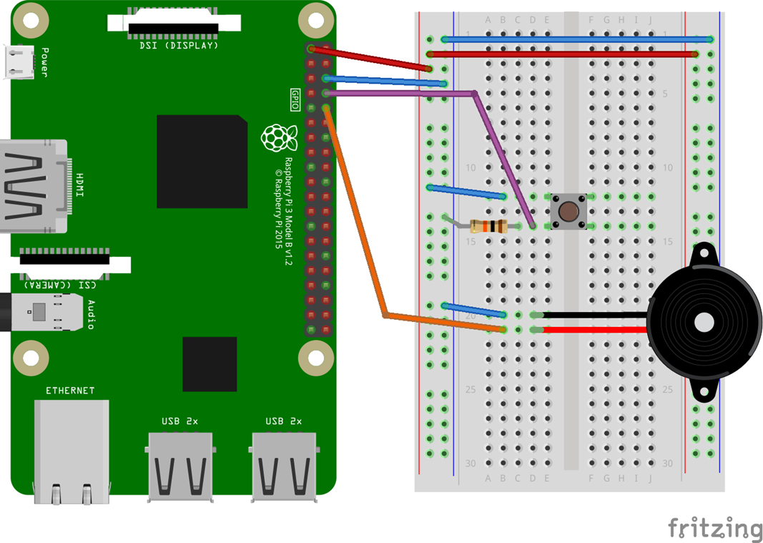
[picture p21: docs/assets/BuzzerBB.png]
    
    \caption{Bread board configuration of the piezoelectric buzzer.}
\end{figure}

\begin{figure}[H]
    \centering
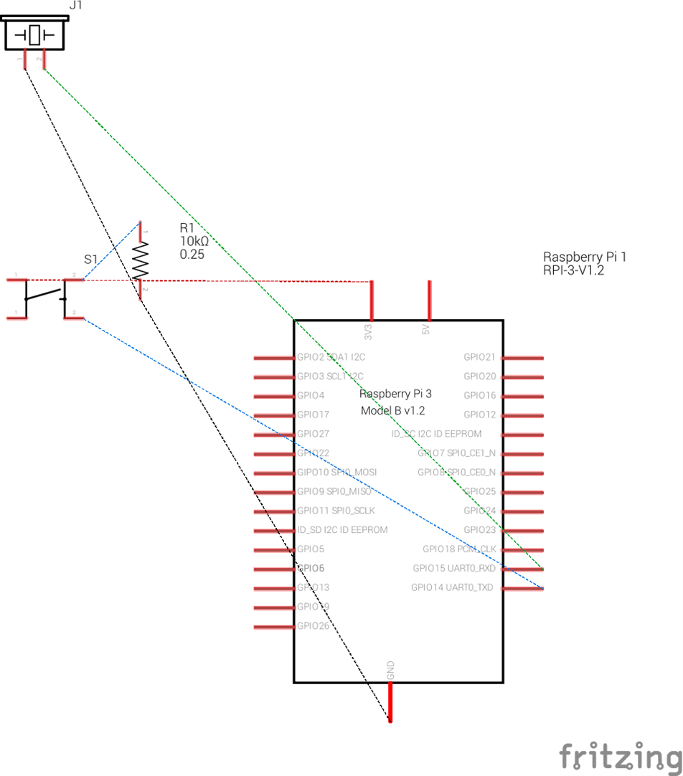
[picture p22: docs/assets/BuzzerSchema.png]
    
    \caption{Schematic of the piezoelectric buzzer circuit.}
\end{figure}

The following schematics show the connections between the piezoelectric buzzer and the Raspberry Pi Pico. There is no
Fritzing footprint for the Pi Pico, so the Raspberry Pi 4 is used as a placeholder.

\begin{figure}[H]
    \centering
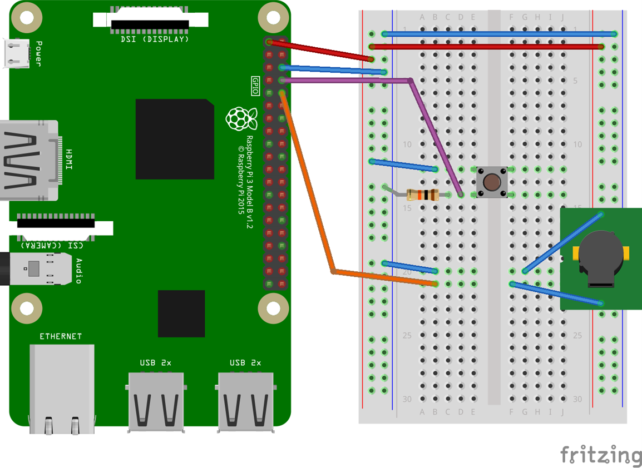
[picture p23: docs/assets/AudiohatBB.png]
    
    \caption{Bread board configuration of the piezoelectric buzzer with the Pi Pico.}
\end{figure}

\begin{figure}[H]
    \centering
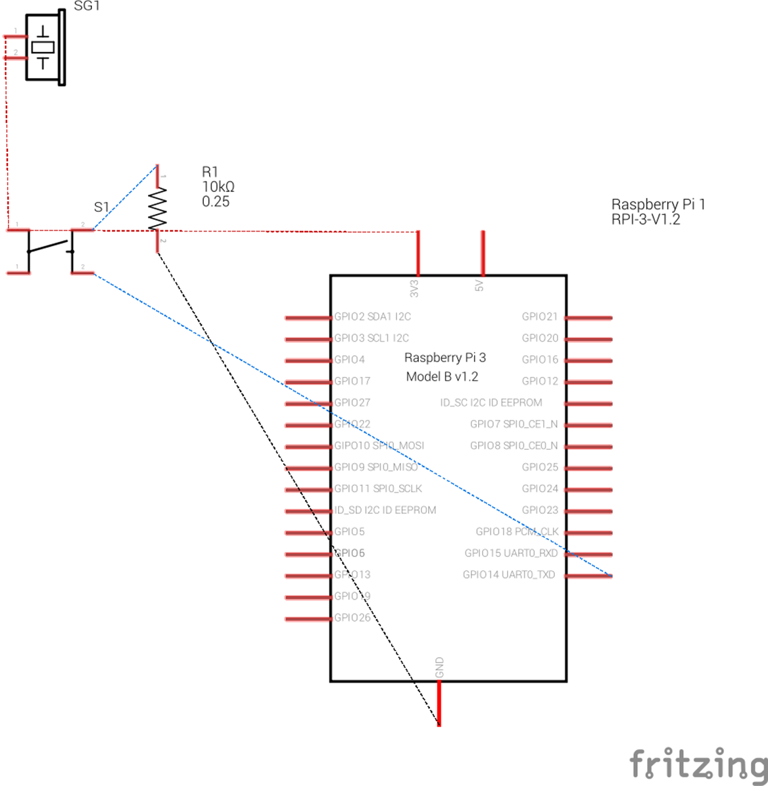
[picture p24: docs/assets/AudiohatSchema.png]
    
    \caption{Schematic of the piezoelectric buzzer circuit connected to the Pi Pico.}
\end{figure}

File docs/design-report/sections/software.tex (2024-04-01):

\section{Software Design}

Each node in the FANS system has its software design outlined below. Simple system nodes with an algorithmic design
have their control flow described using state machine diagrams as an aid. Class diagrams are included for nodes that
use an object-oriented approach for their design.

\subsection{Sensor Data Collection System}

The sensor collection system will be programmed using the Python programming language for simplicity and its large
collection of libraries.

The structure of the program will be that of two continuous polling loops, running as separate processes to utilize the
CPU fully and get around the Global Interpreter Lock (GIL) of Python that prevents maximizing traditional thread
performance.

The first polling loop will be responsible for collecting sensor data continuously and placing it on a queue for the
other loop. It will collect data from all sensors, and that is its sole responsibility.

\begin{figure}[H]
    \centering
    
    \caption{The polling loop for sensor data collection.}
\end{figure}

The second polling loop will be responsible for reading the sensor data from the shared queue and writing it to the
Firebase database. It will also be responsible for performing logical checks on this data to determine whether or not
there is an active fire emergency. It will update the emergency flag in the database whenever a sensor data measurement
is above the specified threshold, and also communicate the emergency over UDP to the notification system and alarm
system. Once all sensor data has been posted to the database, this loop will check for configuration updates in the
sensor data thresholds from the Firebase database and apply them to the next iteration.

\begin{figure}[H]
    \centering
    
    \caption{State machine diagram for the second process of the sensor data collection system.}
\end{figure}

\subsection{Alarm System}

The alarm system will be programmed using the Python programming language, again for its simplicity. The alarm system
will be composed of one continuous loop, which waits to receive incoming UDP messages. When a UDP message signifying an
emergency is received, the alarm system will trigger both an alarm buzzer and flashing LED lights for an infinite
duration. The alarm response will be interrupted only when the system receives another UDP message signifying that the
emergency has ended. This behaviour is similar to a state machine, so the software will be created using the state
design pattern.

\begin{figure}[H]
    \centering
    
    \caption{State machine diagram for the alarm system node.}
\end{figure}

\subsection{Notification System}

The notification system will be written in the Python programming language, also due to its simplicity and availability
of libraries for sending email notifications \cite{python-email}. The notification system will listen for a UDP message
signifying an emergency, and then send out email and SMS notifications to all users in the Firebase database. Once a
UDP message signifying the end of the emergency is received, the system will send a followup email to all users that
the emergency has been resolved.

\begin{figure}[H]
    \centering
    
    \caption{The state machine representing the primary functionality of the notification system.}
\end{figure}

The notification system will keep a local cache of user contact information as a backup for failing internet
connectivity. It will periodically update its local cache with any changes in the upstream Firebase database.

The notification system will also have locally stored email and SMS templates for notifications. These will be loaded
as "Templates", which provide an interface for easy customization and sending of notifications.

\begin{figure}[H]
    \centering
    
    \caption{Class diagram for the notification system node.}
\end{figure}

\subsection{Haptic Alarm System}

The haptic alarm wearable also has a very simple software design, and will be written in the Python programming
language. The program will continuously poll the Firebase database for changes in the emergency flag. Once the
emergency flag has been raised, the haptic alarm will begin to buzz on and off. During this time, it will continue
checking for changes in the emergency flag on the Firebase database. Once the emergency flag is lowered, the haptic
alarm will stop buzzing, signifying the end of the emergency.

\begin{figure}[H]
    \centering
    
    \caption{State machine diagram for the haptic alarm system node.}
\end{figure}

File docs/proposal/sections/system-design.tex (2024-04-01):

\section{System Design}

\subsection{System Overview Diagram}

Figure \ref{fig:deployment} shows the deployment diagram for FANS. There will be three devices which communicate with
each other on a local network:

\begin{enumerate}
    \item The alarm system on a Raspberry Pi 4.
    \item The smoke detection system on a Raspberry Pi 4.
    \item A notification system on a Raspberry Pi 4.
\end{enumerate}

\begin{figure}[H]
    \centering
    
    \caption{Deployment diagram of FANS.}
    \label{fig:deployment}
\end{figure}

The smoke detection and temperature logging system will continuously update the cloud database with recorded smoke and
temperature levels.

When the smoke detection system detects a smoke or temperature measurement above the limiting threshold, it will signal
the alarm system to sound the alarm using a UDP packet. It will also signal the notification system to send out
notifications to the subscriber list in the same way, and then send a write request to the cloud database to signal the
emergency detection flag.

The fourth device, the Pi Pico, will buzz when the cloud database indicates that an emergency has been detected by the
detection system. This will physically notify the user of the emergency.

The notification and alarm system are on separate devices to preserve their integrity in the case of an emergency. It
is possible that the smoke detection system will be closer to the source of the fire, and therefore be at risk of being
damaged/disabled. With the notification and alarm systems on separate devices connected through a local internet
connection, they will be able to perform their responsibilities with less risk of being damaged by flames. The local
connection also allows the alarm to sound in the case where the local network loses internet connection.

The cloud database is a real-time database to facilitate the real-time nature of display information on the web GUI. In
addition, it will allow the haptic feedback device to buzz as soon as the smoke detection system signals an emergency
to the cloud database. The fire alarm system has a real-time nature which needs to be preserved.

The web GUI will be served on the cloud, allowing us to serve our interface to multiple users more easily.

\textbf{Scalability} \\
This configuration would allow us to scale our system horizontally very easily. Multiple different alarm systems and
smoke detectors could be connected over a local network to a notification system, allowing smoke detection in multiple
rooms and alarms sounding in multiple rooms. Additionally, several haptic alarm wearable devices could be clients to
the real-time database, allowing any number of users to be notified haptically in the event of an emergency.

\textbf{Modularity} \\
Each subsystem has a single responsibility that allows for modularity in FANS. Subsystems have a clearly defined
interface with specific messages passed between them, allowing subsystems to operate without knowledge of each others’
implementations.

The smoke detection system simply sends emergency signals out over the local network to nodes who are listening, which
allows it to set off multiple alarm nodes.

The cloud database makes data available in such a way that multiple web UI clients and multiple wearable devices can
access sensor data and emergency flags.

The notification system is entirely self-contained, and only requires access to contact information in the cloud
database.

\subsubsection{Communication Protocols}

The smoke detection system will be communicating with an array of temperature and smoke sensors using the I2C protocol
over the GPIO pins of a Raspberry Pi 4.

Each node on the local network (the smoke detection system, alarm system and notification system) will communicate with
each other using UDP packets over the local network.

Nodes which communicate with the cloud hosted real-time Firebase database will use HTTP requests to interact with the
database.

\begin{itemize}
    \item The smoke detection system will post JSON payloads to the database to write data.
    \item The web GUI will request JSON over HTTP to update its visual components (dashboard with charts, etc.) with the data
          stored in the database.
    \item The notification system will request contact information from the database over HTTP to send notifications to affected
          users.
    \item The haptic alarm system will poll a database flag over HTTP to check if there is an active emergency.
\end{itemize}

Finally, the notification system will communicate with affected users over email and SMS text notifications. This will
use standard internet, SMS and email protocols.

\subsection{Component Details}

The following section will describe the interfaces and responsibilities of each major node in the FANS system.

\subsubsection{Smoke Detection System}

The first component in the proposed system is the smoke detection and temperature sensing system. It will read sensor
data from a locally connected smoke sensor and temperature sensor using the I2C protocol over the Raspberry Pi 4's GPIO
pins. It will then update the real-time Firebase database with the collected sensor data over an internet connection.

If any temperature or smoke measurements are above the critical threshold for signalling an emergency, it will send a
message to the notification system and the alarm system over UDP to signify an emergency. It will also update a flag in
the real-time database to signify that an emergency has been detected.

The smoke detection system can be configured by the user. The user configuration settings will be read from the cloud
database whenever they are updated, which allows the smoke detection system to use configurable smoke and temperature
thresholds and have a time-out.

\begin{figure}[H]
    \centering
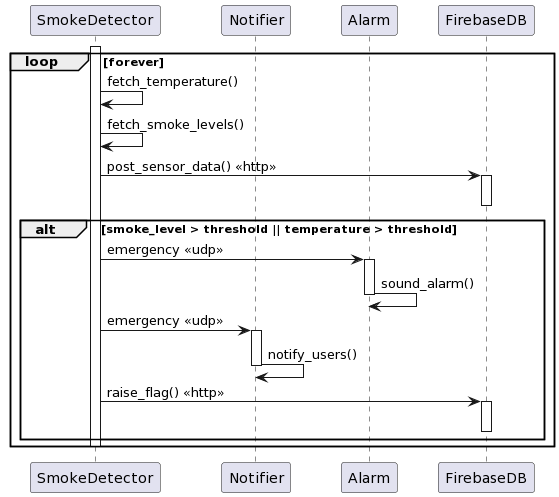
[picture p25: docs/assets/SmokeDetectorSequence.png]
    
    \caption{Sequence diagram for the primary responsibilities of the smoke detector system.}
    \label{fig:smoke-detector-sq}
\end{figure}

\subsubsection{Notification System}

The notification system is responsible for notifying affected users of an emergency and triggering the alarm system. It
will also send SMS and email notifications to all users in the database to notify them of the detected emergency.

The notification system sends its notifications following the receipt of a UDP message from the smoke detection system.
The contact information of the notification recipients are stored both on its local database and the cloud database.
The local database is synchronized periodically with the cloud.

\begin{figure}[H]
    \centering
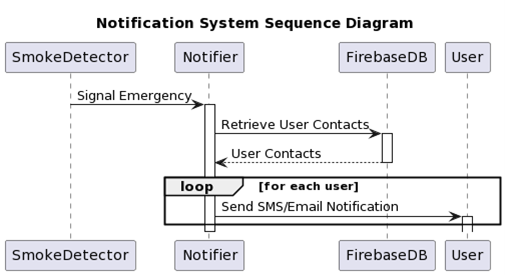
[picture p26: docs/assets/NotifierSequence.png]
    
    \caption{Sequence diagram for the primary responsibilities of the notification system.}
    \label{fig:notifier-sq}
\end{figure}

\subsubsection{Alarm System}

The alarm system is responsible for sounding an alarm in the building when an emergency has been detected. The alarm
system receives notification over UDP from the smoke detection system when an emergency has been detected, at which
point it sounds an alarm and flashes lights.

The lights will be an on-board SenseHat, and the alarm is an audio-hat module. The alarm will continue to sound until
the system receives a UDP message to stop.

\begin{figure}[H]
    \centering
    
    \caption{Sequence diagram for the primary responsibilities of the alarm system.}
\end{figure}

\subsubsection{Haptic Alarm System}

The haptic alarm system is designed to be a wearable device that vibrates during an emergency. The device queries the
real-time database for a flag indicating an alarm. Once the flag is raised, the device vibrates until the emergency has
ended (the flag is "lowered" in the database).

\begin{figure}[H]
    \centering
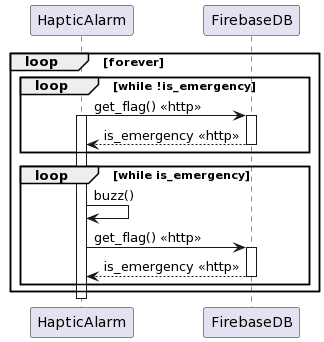
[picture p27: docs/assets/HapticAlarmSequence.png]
    
    \caption{Sequence diagram for the primary responsibilities of the haptic alarm system.}
    \label{fig:haptic-alarm-sq}
\end{figure}

\subsubsection{Firebase Real-Time Database}

The real-time database is responsible for storing smoke and temperature level data in real-time, as well as a database
flag indicating emergency. User contact information will also be stored in this database. Finally, it will also contain
user-configured settings (such as smoke level threshold for triggering an emergency). It will be cloud hosted by
Firebase.

\begin{itemize}
    \item The interaction between the haptic alarm system and the real-time database is visible in Figure
          \ref{fig:haptic-alarm-sq}.

    \item The interaction between the smoke detector system and the real-time database is visible in Figure
          \ref{fig:smoke-detector-sq}.

    \item The interaction between the notification system and the real-time database is visible in Figure \ref{fig:notifier-sq}.

    \item The primary interaction between the web GUI and the real-time database is documented in Figure \ref{fig:webui-sq}, and
          secondary interactions can be seen in Section \ref{s:use-cases}.
\end{itemize}

\subsubsection{Web GUI}

The web GUI is responsible for displaying the sensor information from the real-time database on time-series charts. It
will also allow users to configure settings for FANS (emergency thresholds, etc.) and add more user contact information
to the notification subscriber list. It will also allow users to disable the alarm when an emergency has been resolved.

\begin{figure}[H]
    \centering
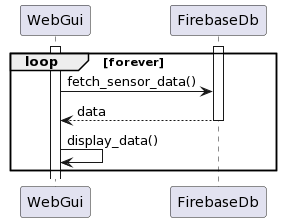
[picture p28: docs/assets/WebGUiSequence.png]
    
    \caption{Sequence diagram for the primary responsibilities of web GUI.}
    \label{fig:webui-sq}
\end{figure}

\subsection{Use Cases} \label{s:use-cases}

\subsubsection{Adding New Contact Information}

\textbf{Actor:} User

\textbf{Preconditions:}
\begin{itemize}
    \item User must be logged into the Web GUI.
    \item user must be authenticated and authorized to make database changes.
\end{itemize}

\textbf{Flow of events:}
\begin{enumerate}
    \item User accesses the web GUI.
    \item User navigates to the section for managing contacts or settings.
    \item User selects the option to add new contact information.
    \item User fills in the required fields such as name, phone number, and email address.
    \item User submits the form to save the new contact information.
    \item The web GUI sends a request to the Firebase Real-Time Database to add the new contact information.
    \item Firebase Real-Time Database confirms the successful addition of the new contact information.
    \item The web GUI displays a confirmation message to the user indicating that the new contact information has been
          successfully added.
\end{enumerate}

\textbf{Postconditions:}
\begin{itemize}
    \item The new contact information is stored in the Firebase Real-Time Database.
    \item The web GUI reflects the updated contact list.
\end{itemize}

\begin{figure}[H]
    \centering
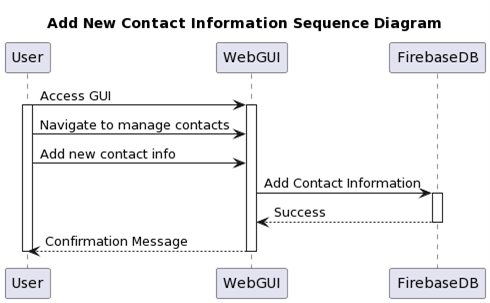
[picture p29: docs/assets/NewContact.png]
    
    \caption{Sequence diagram for the major interactions in the "Add Contact Information" use case.}
\end{figure}

\subsubsection{Change Emergency Threshold}

\textbf{Actor:} User

\textbf{Preconditions:}
\begin{itemize}
    \item User must have access to the web GUI.
    \item User must be authenticated and authorized to make changes to the database.
    \item The smoke detection system must be operational and connected to the Firebase Real-Time Database.
\end{itemize}

\textbf{Flow of events:}
\begin{enumerate}
    \item User accesses the web GUI.
    \item User navigates to the section for managing settings.
    \item User selects the option to change the smoke detection threshold.
    \item User enters the new threshold value.
    \item User submits the form to save the new threshold value.
    \item The web GUI sends a request to the Firebase Real-Time Database to update the smoke detection threshold.
    \item Firebase Real-Time Database confirms the successful update of the threshold value.
    \item The web GUI displays a confirmation message to the user indicating that the threshold value has been successfully
          updated.
\end{enumerate}

\textbf{Postconditions:}
\begin{itemize}
    \item The new smoke detection threshold value is stored in the Firebase Real-Time Database.
    \item The smoke detection system adjusts its threshold for triggering an emergency based on the new value.
    \item The web GUI reflects the updated threshold value.
\end{itemize}

\begin{figure}[H]
    \centering
    
    \caption{Sequence diagram for the major interactions in the "Change Emergency Threshold" use case.}
\end{figure}

\subsubsection{Trigger Emergency}

\textbf{Flow of events}
\begin{enumerate}
    \item The smoke detection system sends a TCP message to the notification system to warn of an emergency.
    \item The smoke detection system raises a flag in the real-time database to indicate the emergency.
    \item The notification system forwards this message to the alarm system.
    \item The notification system begins sending SMS and email notifications to the users who are listed in the database.
    \item The alarm system receives the TCP message from the notification system.
    \item The alarm system sounds the alarm and flashes LEDs.
    \item The haptic alarm system reads the flag from the real-time database.
    \item The haptic alarm system begins buzzing.
\end{enumerate}

\begin{figure}[H]
    \centering
    
    \caption{Sequence diagram for the major interactions in the "Trigger Emergency" use case.}
\end{figure}

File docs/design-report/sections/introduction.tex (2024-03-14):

\section{Problem Statement}

The need for the Fire Alarm Notification System (FANS) stems from the alarming number of preventable fire deaths in
Canada, where 220 people die in fires each year, with at least one in seven of these deaths occurring in homes without
working smoke alarms \cite{fire-stats}. This critical problem underscores the shortcomings of traditional fire alarm
systems, which often lack advanced communication capabilities and real-time monitoring capabilities
\cite{modern-fire-alarms}. These limitations not only contribute to delayed response times, but also to preventable
deaths, underscoring the urgent need for an advanced fire alarm solution.

Traditional systems' shortcomings, coupled with the fact that smoke detection systems are sometimes unsafely disarmed
by users to avoid false alarms—especially those installed close to kitchen spaces—further exacerbate the problem. The
FANS project seeks to address these issues by integrating smoke and temperature sensors with Internet of Things (IoT)
technology. This approach not only aims to cover scenarios where smoke may not reach the detecting device but also
offers real-time notifications via SMS and email, thus notifying homeowners immediately in the event of an emergency.

By providing configurable thresholds for smoke and temperature alarms and adjustable timeouts that prevent the system
from being deactivated in an unsafe manner, FANS aims to use technological advances to significantly improve the
effectiveness of fire detection systems. The ultimate goal of the project is to reduce response times, improve overall
fire safety and thereby mitigate fire disasters and protect the well-being of individuals, families and communities
across Canada \cite{smoke-alarm-gc}.

\subsection{Functional Requirements}

\begin{enumerate}
    \item \textbf{Accurate and Reliable Detection} \\ Implement dual-sensor technology combining photoelectric and thermistor-based
          sensors for accurate smoke and temperature detection, alongside unit testing routines to ensure reliability.

    \item \textbf{Real-time Monitoring and Alerts} \\ Utilize a cloud-based platform for continuous real-time data
          storage, with a reliable communication channel for immediate alert dispatch. The database must be able to
          serve the stored data to multiple clients over an internet connection as it is updated in real-time.

    \item \textbf{User-configurable Sensitivity} \\ Provide an interface for users to customize their alarm
          system sensitivity preferences, including both temperature and smoke detection trigger thresholds.

    \item \textbf{User-defined System Timeout} \\ Provide an interface for users to temporarily disable their alarm
          systems for a pre-determined length of time, allowing the user to avoid triggering emergencies in high-smoke
          environments (such as kitchens).

    \item \textbf{Comprehensive Notification System} \\ Initiate on-site alarms and send email to users and designated contacts to ensure
          widespread awareness during emergencies.

    \item \textbf{Wearable Emergency Response} \\ Incorporate a haptic alarm wearable device that will notify users
          through vibration in active emergency situations. This is ideal for situations where auditory alarms may not
          be effective or where users with hearing impairments are at risk of a fire hazard, ensuring maximum reach and
          effectiveness of alerts.

\end{enumerate}

By adopting these key requirements, FANS aims to deliver a technologically advanced, user-friendly system for timely
fire detection and response, aiming to reduce fire-related fatalities and enhance safety for individuals and
communities across Canada.

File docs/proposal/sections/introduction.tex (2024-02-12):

\section{Introduction}

This document presents the proposal for Fire Alarm Notification System (FANS), a comprehensive solution addressing the
alarming rate of preventable fire deaths in Canada. \cite{smoke-alarm-gc} The L1-G8 group has developed FANS as a
multi-device fire alarm system with advanced features to significantly reduce fire deaths through timely detection and
response to fire emergencies.

The proposal reveals the detailed system design and comprehensive work plan for the development and implementation of
FANS to reduce the number of preventable fire-related deaths in Canada. It outlines the system's architecture and
provides a structured work plan detailing the phases of development, testing and deployment to ensure the timely
release of FANS to effectively mitigate fire disasters.

\subsection{Background}

Every year in Canada, 220 people die from fire-related causes. \cite{fire-stats} At least 1 in 7 of these deaths
occurred in homes without a working smoke alarm. \cite{fire-stats} This is an alarming number of deaths, which FANS
aims to prevent.

As a result of these preventable deaths, the government of Canada has released guidelines for smoke alarm installation
and care. \cite{smoke-alarm-gc} FANS aims to take a modern approach to fire safety by integrating its smoke alarm
system with the Internet of Things (IoT).

Traditional fire alarm systems often lack modern communication features and real-time monitoring capabilities. These
limitations contribute to delays in response time and can lead to preventable fire-related deaths. Modern systems make
use of not only smoke detection sensors, but also heat detectors that can detect a rise in temperature due to fires.
\cite{modern-fire-alarms} Smoke detection systems are also subject to unsafe disarming by users who have their alarm
installed close to their kitchen space. False alarms can be frustrating while cooking, but disabling the smoke alarm is
a dangerous action that puts the user at risk of forgetting to re-enable it. \cite{disabling-alarm}

The FANS project aims to address the shortcomings of traditional systems and implement the strengths of modern systems
by introducing a comprehensive multi-system solution. FANS will use both smoke and temperature sensors to cover
situations where smoke cannot reach the detecting device. It will issue real-time notifications via SMS and email to
notify homeowners of an emergency. Finally, FANS will offer configurable thresholds for smoke and temperature alarms,
as well as configurable timeouts for the system to prevent disgruntled users from unsafely disabling their alarm system
while cooking.

By leveraging technological advancements, FANS seeks to improve the effectiveness of fire alarm systems and reduce
fire-related fatalities in Canada.

\subsection{Motivation}

The motivation for the FANS project is to address the critical problem of preventable fire-related deaths in Canada.
Fire safety is a fundamental concern for individuals, families, and communities nationwide. By leveraging modern
technological advancements, the FANS system aims to significantly enhance the effectiveness of fire alarm systems,
reducing response times, and ultimately saving lives. The importance of this project cannot be overstated, as it
directly impacts the safety and well-being of Canadians.

\subsection{Project Objective}

The overarching objective of the FANS project is to develop and deploy a functional fire detection and notification
system that enhances fire safety. FANS accomplishes this by providing real-time fire detection, timely notifications to
users, and proactive monitoring of environmental conditions.

\subsection{Specific Goals}

The goals that the FANS development team aims to achieve in this project are as follows:

\begin{enumerate}
    \item Develop and test a smoke detection algorithm on a Raspberry Pi to ensure accurate and reliable smoke detection.

    \item Integrate smoke and temperature sensors on the Raspberry Pi to a real-time database for real-time data collection.

    \item Implement a robust notification system capable of triggering alarms at installation sites and sending email alerts to
          users in affected areas.

    \item Allow configurable smoke and temperature alarm thresholds for more control over alarm sensitivity, as well as
          configurable time-out durations on detection units that are close to cooking spaces.

    \item Create a user-friendly web interface for system monitoring and interaction, allowing users to access real-time data
          visualizations on their dashboard. Users should be able to configure system settings, add new user contact information
          to the notification subscriber list, and receive alerts all in the native web UI.

\end{enumerate}

\subsubsection{Functional Requirements}

\begin{enumerate}
    \item Consistent accuracy from the smoke sensors to avoid any false alarms/triggers.

    \item Collected sensor data must be written to the cloud database in real-time for accurate monitoring.

    \item Email and SMS notifications must be sent to all users in the notification subscriber list.

    \item Users will be able to configure smoke and temperature alarm thresholds from the web interface.

    \item Users will be able to set variable length time-outs for the detection unit while they cook. The detection unit will
          become active immediately after the time-out ends.

    \item The web interface must provide time series charts that display both smoke levels and temperature levels as data is
          written to the real-time database.

    \item The detection unit must be able to signal an emergency to the both the alarm unit and the notification unit over the
          local network.
\end{enumerate}

\subsubsection{Non-Functional Requirements}

\begin{enumerate}
    \item The system must be highly reliable and available to ensure immediate response during emergencies.

    \item The system should scale easily to accommodate a growing number of users and installation sites.

    \item There must be data security and privacy measures to protect sensitive contact information.
\end{enumerate}

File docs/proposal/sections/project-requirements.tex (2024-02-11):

\section{Project Requirements Checklist}

\textbf{Computer Components}

\begin{itemize}
    \item 1 Raspberry Pi per each of the following: Smoke Detector device, Smoke Alarm, Wearable Accessory
    \item 1 Raspberry Pi will be used to transfer info to and from all the other RPis to the Web GUI (running in headless mode). There are 4 Raspberry Pi’s used in the project overall.
\end{itemize}

\textbf{Hardware Components}

\begin{itemize}
    \item MQ2 Smoke Sensor (x1), LCD Display (x2), AudioHat Module (x1), SenseHat Module (x1)
    \item Actuator: LCD Display, AudioHat Module
    \item Smoke sensor waits till it senses smoke, once that requirement is met it triggers the alarm, wearable accessory, and
          sends a notification to the Web GUI
\end{itemize}

\textbf{Software Components}

\begin{itemize}
    \item Database for employee contact information.
    \item The computer hosting the database changes depending on user configurations (Level of smoke to detect, Web GUI themes,
          alarm sounds).
    \item Database includes a table for user info (employee names, phone numbers, emergency numbers) and another table for sensor
          data (temperature data, smoke detection).
    \item Periodic timing loop is given by the smoke sensor monitoring the environment for smoke. The smoker sensor will log this
          data and send it to the web GUI every minute.
    \item The data the smoke detector logs will be displayed on the user website in the form of varying graphs and widgets.
    \item Smart watch will have a buzzer, Raspberry Pi with the alarm will have notification software. Raspberry Pi will send
          notifications to the Smart watch and to the web GUI.
    \item Bidirectional GUI included (user can reset the smoke detector from the web GUI, and changes made to the physical
          detector will show in Web GUI settings)
\end{itemize}

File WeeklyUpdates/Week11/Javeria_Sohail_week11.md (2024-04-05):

## Weekly Individual Project Update Report

### Group number: L1-G8

### Student name: Javeria Sohail

### Week: 11 (20 Mar - 26 Mar)

---

1. **How many hours did you spend on the project this week? (0-10)**

I spent 14 hours on the project this week.

2. **Give rough breakdown of hours spent on 1-3 of the following:\***
   (meetings, information gathering, design, research, brainstorming, evaluating options, prototyping options, writing/documenting, refactoring, testing, software implementation, hardware implementation)

   1. Completed the implementation of the Pico Haptic Alarm (5 hours)
   2. Worked on the draft final report (1 hour)
   3. Filmed final demo video with group members and on my own (4 hours)
   4. Added my updated PEP8 code on Github (2 hour)
   5. Created new schematics for my breadboard circuits and wrote installation instructions (2 hour)

3. **_What did you accomplish this week?_** _(Be specific)_

   - Completed the implementation of the haptic alarm on Raspberry Pico
   - Worked on the draft final report 
   - Filmed final demo video with group members and on my own
   - Made my code conform to PEP8
   - Created new schematics for my breadboard circuits using Fritzing and wrote installation instructions
     
4. **_How do you feel about your progress?_** _(brief, free-form reflection)_

- This week had a very heavy workload, which was difficult to balance with other courses and the Feedback fruits takes so much time.
- I'm confident in our system's features now, although the UI may need a little more polishing before the lab demo.
- I am just concerned our video might not be of the best quality but I am pretty proud of my team.

5. **_What are you planning to do next week_**? _(give specific goals)_

- Complete the term reflection
- Get all final features solidified before the lab demo on Thursday
- Complete the final report
- Ensure that the code base conforms to proper standards and meets rubric expectations before submitting

6. **_Is anything blocking you that you need from others?_** _(What do you need from whom)_

- I just want to see the final video and review it before it's submitted on Wednesday!

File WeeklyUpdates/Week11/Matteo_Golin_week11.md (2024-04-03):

## Weekly Individual Project Update Report

### Group number: L1-G8

### Student name: Matteo Golin

### Week: 11 (20 Mar - 26 Mar)

---

1. **How many hours did you spend on the project this week? (0-10)**

I spent 18 hours on the project this week.

2. **Give rough breakdown of hours spent on 1-3 of the following:\***
   (meetings, information gathering, design, research, brainstorming, evaluating options, prototyping options, writing/documenting, refactoring, testing, software implementation, hardware implementation)

   1. Completed the implementation of the smoke detector circuit (2 hours)
   2. Added charts to the web GUI and setting of thresholds (3 hours)
   3. Added timeout feature to the web GUI and the sensor collection system (2 hours)
   4. Worked on the draft final report (1 hour)
   5. Filmed final demo video with group members and on my own (6 hours)
   6. Added GitHub workflows to repository and made my code conform to PEP8 (2 hour)
   7. Created new schematics for my breadboard circuits and wrote installation instructions (1 hour)
   8. Attempted to create housing boxes for each Pi-based node (1 hour)

3. **_What did you accomplish this week?_** _(Be specific)_

   - Completed the implementation of the smoke detector circuit to gather smoke concentration measurements
   - Added charts to the web GUI and setting of thresholds
   - Added timeout feature to the web GUI and the sensor collection system
   - Worked on the draft final report deployment diagram, contributions and reflections sections
   - Filmed final demo video with group members and on my own
   - Added GitHub workflows to repository for linting and formatting, and made my code conform to PEP8
   - Created new schematics for my breadboard circuits using KiCad and wrote installation instructions
   - Attempted to create housing boxes for each Pi-based node

4. **_How do you feel about your progress?_** _(brief, free-form reflection)_

- This week had a very heavy workload, which was difficult to balance with other courses
- I'm confident in our system's features now, although the UI may need a little more polishing before the lab demo
- I'm concerned about the quality of the video recorded for the final demo reflections because we had so little time
  this weekend

5. **_What are you planning to do next week_**? _(give specific goals)_

- Complete the term reflection
- Get all final features solidified before the lab demo on Thursday
- Complete the final report
- Ensure that the code base conforms to proper standards and meets rubric expectations before submitting

6. **_Is anything blocking you that you need from others?_** _(What do you need from whom)_

- I just want to see the final video and review it before it's submitted on Wednesday!

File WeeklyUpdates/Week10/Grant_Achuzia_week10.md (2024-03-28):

## Weekly Individual Project Update Report

### Group number: L1-G8

### Student name: Grant Achuzia

### Week: 10,  Wednesday March 20th 2024 - Tuesday March 26th 2024

---

1. **How many hours did you spend on the project this week? (0-10)**

I spent 4 hours working on the project this week.

2. **Give rough breakdown of hours spent on 1-3 of the following:\***
   (meetings, information gathering, design, research, brainstorming, evaluating options, prototyping options, writing/documenting, refactoring, testing, software implementation, hardware implementation)

   1. Learning more about the pico w and its capabilities, 2 hours
   2. Designing and building a draft haptic alarm with the pico w, 2 hour

3. **_What did you accomplish this week?_** _(Be specific)_

- Began configuring the pico w's wifi, along with the basic circuitry for the haptic alarm.
- Converting team mates python code to micropython code for the pico w

4. **_How do you feel about your progress?_** _(brief, free-form reflection)_

- Anxious, we have a lot of stuff due in the next 2 weeks, and exams are also coming up soon.

5. **_What are you planning to do next week_**? _(give specific goals)_

- Add user authentication to web app
- Configure the pico w to work with our firebase system

6. **_Is anything blocking you that you need from others?_** _(What do you need from whom)_

- None at the moment.

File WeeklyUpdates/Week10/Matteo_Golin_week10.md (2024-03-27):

## Weekly Individual Project Update Report

### Group number: L1-G8

### Student name: Matteo Golin

### Week: 10 (20 Mar - 26 Mar)

---

1. **How many hours did you spend on the project this week? (0-10)**

I spent 5 hours this week.

2. **Give rough breakdown of hours spent on 1-3 of the following:\***
   (meetings, information gathering, design, research, brainstorming, evaluating options, prototyping options, writing/documenting, refactoring, testing, software implementation, hardware implementation)

   1. Researching how to interface with smoke sensor (1 hour)
   2. Making the sensor collection program and alarm system multi-threaded (4 hours)

3. **_What did you accomplish this week?_** _(Be specific)_

- My group purchased the smoke sensor parts required for interfacing with the Pi
- I made the smoke sensor program and the alarm system multi-threaded for more responsive event handling

4. **_How do you feel about your progress?_** _(brief, free-form reflection)_

- I'm worried since there are many deliverables due shortly (final report, demo video)
- The smoke sensor is quite complex to interface with the Pi

5. **_What are you planning to do next week_**? _(give specific goals)_

- Complete the integration of the smoke sensor
- Poll Firebase to check for user timeouts and manual disabling of the active emergency
- Aid team members in polishing their work

6. **_Is anything blocking you that you need from others?_** _(What do you need from whom)_

- Not at this time!

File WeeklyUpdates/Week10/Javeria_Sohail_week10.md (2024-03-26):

## Weekly Individual Project Update Report

### Group number: L1-G8

### Student name: Javeria Sohail

### Week: 10 (19Mar - 26 Mar)

---

1. **How many hours did you spend on the project this week? (0-10)**

I dedicated 8 hours to the project this week.

2. **Give rough breakdown of hours spent on 1-3 of the following:\***
   (meetings, information gathering, design, research, brainstorming, evaluating options, prototyping options, writing/documenting, refactoring, testing, software implementation, hardware implementation)

   1. Getting the Pico to work with the buzzer: 5 hours
   2. Working on the Technical Memo: 2 hours
   3. Demo of the unit tests preperation: 1 hr

3. **_What did you accomplish this week?_** _(Be specific)_

- Decomposed the main script into functions to facilitate testing and got reviews for the technical memo from peers.
- Acquired knowledge on setting up the PiCo 

4. **_How do you feel about your progress?_** _(brief, free-form reflection)_

- I'm very pleased with my progress this week, especially because we've nearly completed the project. 

5. **_What are you planning to do next week_**? _(give specific goals)_

- I plan to focus on developing the pico and LED, aiming to finalize this critical component of our project.

6. **_Is anything blocking you that you need from others?_** _(What do you need from whom)_

- No

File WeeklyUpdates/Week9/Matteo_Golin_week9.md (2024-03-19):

## Weekly Individual Project Update Report

### Group number: L1-G8

### Student name: Matteo Golin

### Week: 9 (13 Mar - 19 Mar)

---

1. **How many hours did you spend on the project this week? (0-10)**

I spent 8 hours this week.

2. **Give rough breakdown of hours spent on 1-3 of the following:\***
   (meetings, information gathering, design, research, brainstorming, evaluating options, prototyping options, writing/documenting, refactoring, testing, software implementation, hardware implementation)

   1. Creating unit tests for the alarm system and building its circuit: 5 hours
   2. Working on the technical memo: 3 hours

3. **_What did you accomplish this week?_** _(Be specific)_

- I learned how to interact with our passive buzzer component to produce alarm noise
- I modified our state machine pattern to be more easily testable
- I wrote unit tests for the alarm system state machine

4. **_How do you feel about your progress?_** _(brief, free-form reflection)_

- I feel great about my progress this week since our alarm system is working

5. **_What are you planning to do next week_**? _(give specific goals)_

- Next week I'd like to work on integrating the smoke sensor since we now have an ADC

6. **_Is anything blocking you that you need from others?_** _(What do you need from whom)_

- I noticed that the passive buzzer is quite quiet when driven only by the Pi's GPIO pins. I know that a higher voltage
  makes a louder buzz, so I wanted to use a BJT transistor or an op-amp to amplify the voltage signal of the Pi's GPIO
  pin. Unfortunately the maker space had neither so I will need to look elsewhere this week

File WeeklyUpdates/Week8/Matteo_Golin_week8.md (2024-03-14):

## Weekly Individual Project Update Report

### Group number: L1-G8

### Student name: Matteo Golin

### Week: 8 (6 Mar - 12 Mar)

---

1. **How many hours did you spend on the project this week? (0-10)**

I spent 8 hours this week.

2. **Give rough breakdown of hours spent on 1-3 of the following:\***
   (meetings, information gathering, design, research, brainstorming, evaluating options, prototyping options, writing/documenting, refactoring, testing, software implementation, hardware implementation)

   1. Writing the final project detailed design document: 5 hours
   2. Working on unit tests for the sensor data collection system: 3 hours

3. **_What did you accomplish this week?_** _(Be specific)_

- The final copy of the detailed design document
- End-to-end communication of the entire system
- Unit tests for the sensor data collection system

4. **_How do you feel about your progress?_** _(brief, free-form reflection)_

- I am feeling much better regarding our progress seeing our successful end-to-end demo
- I am worried about the UI being a very complex node to integrate (especially with user authentication)

5. **_What are you planning to do next week_**? _(give specific goals)_

- Complete unit tests for all system nodes
- Complete the technical memo

6. **_Is anything blocking you that you need from others?_** _(What do you need from whom)_

- We are waiting to hear from ITS services whether or not Carleton has an ADC compatible with our smoke sensor before we
  purchase a new one

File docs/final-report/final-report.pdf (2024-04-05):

## SYSC3010 Computer Systems Development Project FANS Final Report

Group L1-G8


[1]

Grant Achuzia, 101222695
Javeria Sohail, 101197163
Matteo Golin, 101220709
Saja Fawagreh, 101217326
TA: Sean Kirkby

Created: April 3rd, 2024
Modified: April 4, 2024

## Contents

1 Project Description | 3
2 Final Solution | 5
3 Discussion of Final Design | 11
4 Contributions | 13
A GitHub Repository README | 16

## 1 Project Description

### 1.1 Motivation

The motivation for the FANS project was to address the critical problem of preventable firerelated deaths in Canada. Fire safety was a fundamental concern for individuals, families, and communities nationwide. By leveraging modern technological advancements, the FANS system aimed to significantly enhance the effectiveness of fire alarm systems, reducing response times, and ultimately saving lives. The importance of this project could not be overstated, as it directly impacted the safety and well-being of Canadians.

### 1.2 Problem Statement

The need for the Fire Alarm Notification System (FANS) stemmed from the alarming number of preventable fire deaths in Canada, where 220 people died in fires each year, with at least one in seven of these deaths occurring in homes without working smoke alarms [2]. This critical problem underscored the shortcomings of traditional fire alarm systems, which often lacked advanced communication capabilities and real-time monitoring capabilities [3]. These limitations not only contributed to delayed response times but also to preventable deaths, underscoring the urgent need for an advanced fire alarm solution.

Traditional systems’ shortcomings, coupled with the fact that smoke detection systems were sometimes unsafely disarmed by users to avoid false alarms—especially those installed close to kitchen spaces—further exacerbated the problem. The FANS project sought to address these issues by integrating smoke and temperature sensors with Internet of Things (IoT) technology. This approach not only aimed to cover scenarios where smoke may not reach the detecting device but also offered real-time notifications via SMS and email, thus notifying homeowners immediately in the event of an emergency.

By providing configurable thresholds for smoke and temperature alarms and adjustable timeouts that prevented the system from being deactivated in an unsafe manner, FANS aimed to use technological advances to significantly improve the effectiveness of fire detection systems. The ultimate goal of the project was to reduce response times, improve overall fire safety, and thereby mitigate fire disasters and protect the well-being of individuals, families, and communities across Canada [4].

### 1.3 Overview of Solution

In our project, we implemented the Fire Alarm Notification System (FANS), a real-time system designed for efficient fire detection and alerting. The system comprised several key components, seamlessly integrated to ensure a comprehensive approach to fire safety. We outlined the system’s architecture in a detailed deployment diagram, illustrating the interconnections between the various components.

The Alarm System, based on a Raspberry Pi 4, triggered audible and visual alerts promptly in the event of a fire, ensuring occupants were promptly warned. Our Smoke Detection System, also utilizing a Raspberry Pi 4, continuously monitored the environment for smoke using advanced sensors. It served as the primary detection mechanism, activating the alarm and notification systems upon detecting smoke.

Our Notification System, operating on a Raspberry Pi 4, promptly sent out emergency alerts to predefined contacts, including local authorities and individuals, ensuring rapid response to the detected fire. We employed a real-time cloud database to store critical data, facilitating remote monitoring and configuration, thus ensuring optimal system functionality.

Additionally, we utilized a Pi Pico Device to provide haptic feedback, offering an additional layer of alert through physical sensation, ensuring even those outside the hearing range of the alarm or with hearing impairments were alerted.

Our design emphasized scalability, enabling easy expansion with additional sensors or alarm units as needed. Each component functioned independently, ensuring reliability and ease of maintenance. Communication between components was facilitated through a local network, with the cloud database supporting remote access and control. We incorporated advanced communication protocols for efficient data exchange and alerting. The smoke detection system employed the I2C protocol for sensor communication, while UDP packets facilitated local network communication between the system’s nodes. HTTP requests were utilized for interactions with the cloud-hosted real-time Firebase database, ensuring timely updates and access to system data.


Figure 1: The FANS deployment diagram.

## 2 Final Solution

The final solution for FANS is displayed in Figure 1. This solution uses a distributed systems approach to create a multi-node fire response system controlled via a web interface.

### 2.1 Deployment Diagram

The primary node in the FANS system is the sensor data collection node, which monitors temperature and smoke concentration levels. All sensor measurements are written to the Firebase cloud database for display by the web UI.

When a measurement is detected above the user-defined threshold, the sensor data collection node sends a UDP message signifying an emergency over the local network to the notification system and alarm system nodes. Upon receipt of this message, the notification system will send emails and SMS notifications to all users in its local database. The alarm system node will begin blinking an LED and sounding an alarm.

In addition to the UDP message, the sensor data collection node will raise an emergency flag in the Firebase database which signifies to the UI and the wearable haptic alarm that an emergency is active. The haptic alarm wearable device will then begin blinking an LED and buzzing until the user disables it or the emergency ends.

The UI provides an interface for checking on the status of an emergency and reviewing sensor data in real-time. Users can disable the emergency response from the UI when the emergency has been resolved, and they can also time out the system’s emergency response in scenarios where the system may be falsely triggered (smokey cooking). Finally, the UI also provides an interface for user contact information to be added to the subscriber list for emergency notifications.

Sender | Receiver | Message | Data Format | Protocol
Raspberry Pi 4 | Temperature Sensor | read temp | See section 6.2.1 of datasheet [5] | I2C
Raspberry Pi 4 | Smoke Sensor (via ADC) | read smoke | See figure 1.1 of datasheet [6] | SPI [6]

Table 1: Messages for I2C communication in FANS.

Message | Value
Emergency | 0
No Emergency | 1

Table 2: Numerical representation of messages over UDP in FANS.

### 2.2 Message Protocol Table

In the Fire Alarm Notification System (FANS), a variety of communication protocols are meticulously integrated to ensure seamless interaction among the system components and with the external cloud database, facilitating a robust and responsive fire alarm solution.

The system’s core, the Smoke Detection System, communicates with its temperature and smoke sensors using the I2C and SPI protocols over the GPIO pins of a Raspberry Pi 4.

### 2.2.1 I2C & SPI Communication

The Raspberry Pi 4 utilizes the I2C and SPI protocol to communicate with temperature and smoke sensors, monitoring environmental conditions to detect potential fire hazards. These messages are outlined in 1.

### 2.2.2 Local Area Network Communication

Nodes within the FANS (smoke detection, alarm, and notification systems) communicate over a local network using UDP packets, facilitating real-time alerts and system coordination. The messages sent over UDP use numerical value to encode messages. The representation agreed upon is shown in Table 2. The messages sent are in Table 3

### 2.2.3 Cloud Database Communication

Messages between each node and the Firebase database are shown in Table 4.

Listing 1: Update sensor data message.

1 {
2 | " method ": " PUT ",
3 | " path ": "/ sensor - data / temperature ",
4 | " headers ": {
5 | " Authorization ": " Bearer YOUR_ACCESS_TOKEN ",
Sender | Receiver | Message | Data Format | Protocol
Smoke detection system | Notification system | Emergency | 0 | UDP
Smoke detection system | Alarm system | Emergency | 0 | UDP
Smoke detection system | Notification system | No emergency | 1 | UDP
Smoke detection system | Alarm system | No Emergency | 1 | UDP

Table 3: Messages for local area network communication in FANS.

Sender | Receiver | Message | Data Format | Protocol
Smoke Detection | Cloud DB | put sensor data() | See listing 1 | HTTP (JSON)
GUI | Cloud DB | update threshold(new threshold) | See listing 2 | HTTP (JSON)
Notification | Cloud DB | query contact information() | See listing 3 | HTTP (JSON)
Haptic Alarm | Cloud DB | emergency() | See listing 4 | HTTP (JSON)
GUI | Cloud DB | get sensor data() | See listing 5 | HTTP (JSON)

Table 4: Messages for cloud database communication in FANS.

6 | " Content - Type ": " application / json "
7 | },
8 | " body ": {
9 | " data ": {
10 | " temperature ": 21.2,
11 | " timestamp ": "2024-03-13T08:37:22"
12 | }
13 | }
14 }

Listing 2: Threshold update message.

1 {
2 | " method ": " PUT ",
3 | " path ": "/ system / threshold ",
4 | " headers ": {
5 | " Authorization ": " Bearer YOUR_ACCESS_TOKEN ",
6 | " Content - Type ": " application / json "
7 | },
8 | " body ": {
9 | " newThreshold ": 50
10 | }
11 }

Listing 3: Request for user contact information.

1 {
2 | " method ": " GET ",
3 | " path ": "/ user / contact ",
4 | " headers ": {
5 | " Authorization ": " Bearer YOUR_ACCESS_TOKEN "
6 | }
7 }

Listing 4: Request for emergency flag.

1 {
2 | " method ": " GET ",
3 | " path ": "/ system / emergency ",
4 | " headers ": {
5 | " Authorization ": " Bearer YOUR_ACCESS_TOKEN "
6 | }
7 }

Listing 5: Request for latest sensor data.

1 {
2 | " method ": " GET ",
3 | " path ": "/ sensor - data ",
4 | " headers ": {
5 | " Authorization ": " Bearer YOUR_ACCESS_TOKEN "
6 | }
7 }

### 2.2.4 User Notification Communication

The notification system communicates with users through email, employing standard internet protocols to ensure timely and effective alerts.


Figure 2: The sequence diagram for the trigger emergency use case.

Sender | Receiver | Message | Data Format | Protocol
Notification System | User Inbox | Emergency notification | See listing 6 | SMTP (Email)

Table 5: Messages for user notification communication in FANS.

Listing 6: Email notification for detected emergency in FANS.

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

Dear [ User ’ s Name ] ,

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

Stay s a f e !

### 2.3 Sequence Diagrams

The FANS system will satisfy six core use cases highlighted and illustrated in the message sequence diagrams below.

### 2.3.1 Trigger Emergency Use Case

The trigger emergency use case shown in Figure 2 represents the critical functionality of the FANS, where the system detects a potential fire through its smoke detection system and initiates a series of automated responses to mitigate the situation. As depicted in the message sequence diagram, the process begins when the smoke detection system identifies smoke and potentially high temperatures indicative of a fire. This detection triggers the system to send a notification to the alarm system and the notification system. The alarm system responds by sounding an audible and visible alert to notify occupants of the building immediately. Concurrently, the notification system sends out emergency alerts via SMS and email to all registered users, ensuring they are informed of the danger regardless of their current location. This response ensures that all the users are promptly alerted to the emergency, resulting in a quick evacuation and response to the detected threat.

### 2.3.2 Add New Contact Information Use Case

This use case shown in Figure 3 outlined the process by which users added new contact information to the FANS database. Through the web GUI, users entered new contact details such as phone


Figure 3: The sequence diagram for the adding new contact information use case.


Figure 4: The sequence diagram for the changing emergency threshold use case.

numbers and email addresses, enabling the system to send emergency notifications. Upon submission, these details were successfully updated in the real-time database. The message sequence diagram for this use case (not shown) illustrated the interactions between the user, the web GUI, and the database, culminating in the notification system being updated with the new contact information. This ensured that the FANS could reach the user through various channels in the event of an emergency, thereby enhancing the system’s effectiveness in communicating critical alerts.

### 2.3.3 Change Emergency Threshold Use Case

Adjusting the smoke detection threshold was an essential feature that allowed users to customize the sensitivity of the FANS based on environmental conditions and personal preferences. This use case shown in 4 involved a user accessing the web GUI to modify the threshold settings determining when the smoke detection system should trigger an alert. The message sequence diagram (not shown) visualized the steps involved, from the user’s interaction with the GUI to update the threshold to the real-time database’s role in storing this new setting. The smoke detection system then retrieved and applied the updated threshold, ensuring that the FANS operated according to the user’s specifications, balancing sensitivity and minimizing false alarms.


Figure 5: The sequence diagram for the emergency response use case.

### 2.3.4 Emergency Response Use Case

The scenario in Figure 5 highlights the FANS’s capability to notify users in the event of a detected fire. Upon detecting a fire, the notification system successfully queried the cloud database for contact information and then sent out alerts via SMS and email to all users. The message sequence diagram for this use case (provided above) captured the sequence of these interactions, showcasing how the system ensured that occupants were informed and ready to address the emergency promptly.
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

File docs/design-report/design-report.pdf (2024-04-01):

## SYSC3010 Computer Systems Development Project FANS Detailed Design Report

Group L1-G8

[1]

Grant Achuzia, 101222695
Javeria Sohail, 101197163
Matteo Golin, 101220709
Saja Fawagreh, 101217326
TA: Sean Kirkby

Created: March 11th, 2024
Modified: April 1, 2024

## Contents

1 Problem Statement | 3
2 Design Overview | 5
3 Software Design | 15
4 Hardware Design | 20
5 GUI Design | 24
6 Test Plans | 27
7 Project Update | 32

## 1 Problem Statement
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

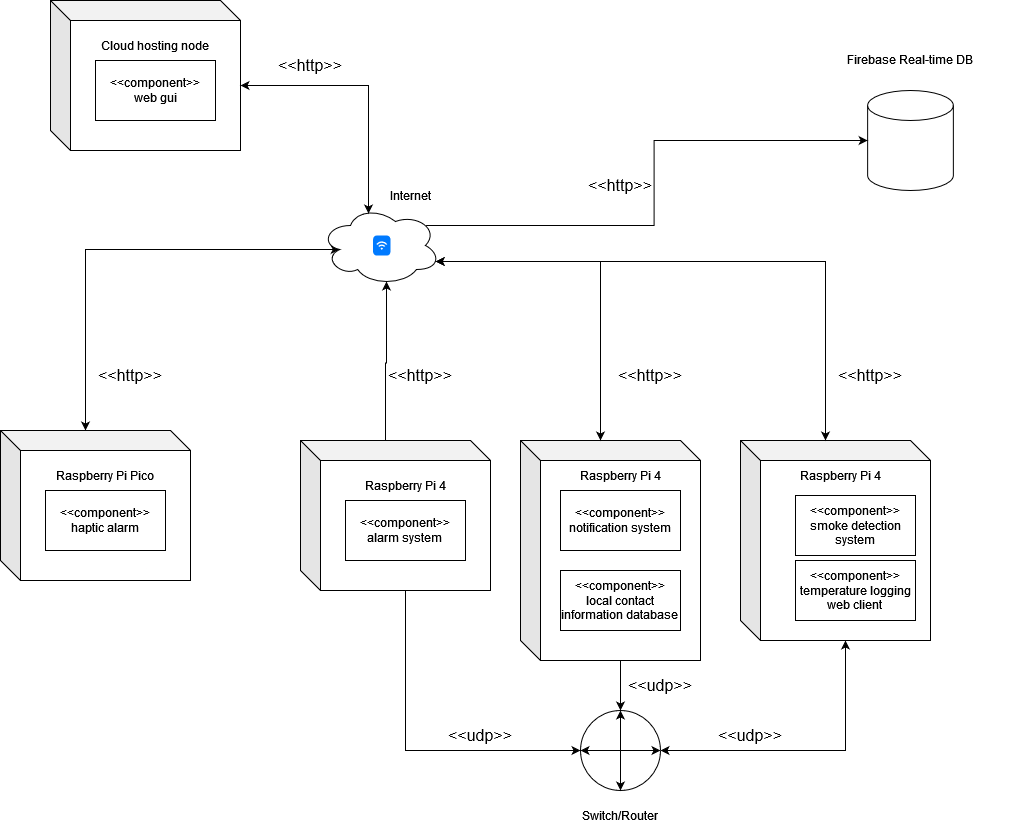
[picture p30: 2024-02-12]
docs/assets/FANSDeployment.png

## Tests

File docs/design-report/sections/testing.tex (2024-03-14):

\section{Test Plans}

Testing is an important part of any system's design. It ensures that project iterations follow the specification,
behave appropriately and are less likely to include bugs.

\subsection{End-to-end Communication Demo}

The end-to-end communication demo should demonstrate all of the major forms of communication present in the FANS
system. In order to achieve this level of demonstration, the following communication examples will be showcased:

\begin{itemize}
    \item Sensor data upload to Firebase over internet.
    \item Email notifications to affected users over internet (email protocol).
    \item Haptic alarm buzzing in accordance with emergency flag in Firebase over internet.
    \item Display of sensor data on the user interface over internet.
    \item Emergency signal from sensor data collection system to the alarm system on local network.
\end{itemize}

It should be noted that the test for the sensor data upload over internet also demonstrates I2C communication between
the Pi 4 and the SenseHat board.

First is the uploading of sensor data to the Firebase database over the internet. For this communication sequence, the
sensor data collection system will be run on one of the Raspberry Pis. It will read temperature data from the SenseHat
and post this data to the Firebase database using Pyrebase. The demonstration can be verified by watching the Firebase
database console, since the data will be updated in real-time.

Second will be the email notifications to affected users over the internet using email protocol. To achieve this
demonstration, the email notification system will be run on one of the Raspberry Pis. Using Pytest, the program will
first send an email from the FANS email back to itself. Then, the program will use \texttt{imaplib} to login to the
FANS email account and verify that the latest message in its inbox contains the same email message that was sent in the
test. If the messages match, Pytest will report a success. This test is fully automated.

Next is the haptic alarm buzzing. For this test, the haptic alarm program will be run on one of the Raspberry Pi's to
emulate the Pi Pico (as it has not arrived at the time of writing). When the program is run, it will poll the Firebase
database using \texttt{pyrebase} to check if the emergency flag has been raised. The flag can either be raised by hand
(the tester modifies the flag using the Firebase console) or it can be set by running the sensor data collection system
with a low emergency reporting threshold for temperature. In either case, when the flag is raised, the output of the
haptic alarm can be verified by observing the console messages. Console printing will be used in place of the buzzer
actuator while we wait for components. A console message of "buzz" would indicate the buzzer buzzing, and no console
messages indicate no emergency while the alarm is polling the database.

To test the display of sensor data collection on the user interface, the GUI will be run on one of the Raspberry Pis
using Flask. When a user clicks the "refresh" button, the Flask API endpoint responsible for returning temperature data
will be hit. The endpoint will use \texttt{pyrebase} to request the latest temperature data from Firebase and then will
respond with JSON. The GUI's JavaScript logic will simply print this JSON as text content of an HTML paragraph tag to
show that the connection is present.

Finally, to demonstrate UDP communication over the local area network, both the sensor data collection system and the
alarm system will be run on two separate Pis. Both programs will first upload their public IP to the Firebase database
under a 'devices' table, and then read the other device's IP. The sensor data collection system should have a
sufficiently low emergency threshold to trigger an emergency at room temperature (only for testing purposes). Once the
sensor data collection system detects an emergency, it will send a UDP message containing the numerical data '0' (the
agreed upon encoding for signifying an emergency) over the LAN addressed to the alarm system. The alarm system will
receive the emergency notification, and instead of activating an actuator it will print "Received 0" to the console.
This can be manually verified.

\subsection{Unit Test Demo}

The purpose of the unit test demo is to demonstrate that the individual components of our system behave as expected and
do not contain logical or physical errors. This will sanity check our hardware components and our software logic.

\subsubsection{Hardware}

The hardware components that will need to be tested are:

\begin{itemize}
    \item Smoke sensor
    \item Temperature sensor
    \item Piezoelectric buzzer
    \item LCD screen
\end{itemize}

\textbf{Smoke Detector}

The smoke detector will be difficult to test due to the nature of what it measures. It will not be possible to light a
fire within the school or near campus because that will set of existing fire suppression systems and may be dangerous.
Testing the smoke detector in smokey environments can be done by:

\begin{itemize}
    \item Running the data collection from the smoke detector in a smoking zone on campus.
    \item Running the data collection from the smoke detector off campus and lighting a fire nearby.
\end{itemize}

For both of these tests, it should be verified that smoke levels are detected. This will be a one-time sanity test of
the sensor. The smoke detector can also be tested in smokeless environments by collecting data from the sensor indoors
on campus and ensuring that no smoke is detected.

\textbf{Temperature Sensor}

To test the temperature sensor, we can collect data from the sensor in the lab setting and ensure that measurements are
within the acceptable range for room temperature.

\textbf{Piezoelectric Buzzer}

To test the piezoelectric buzzer, we can test turning on and off the buzzer and verifying that it produces noise.
Additionally, we can set the buzzer to produce different frequencies and verify that they are set correctly by checking
with a instrument tuning app.

\textbf{LCD Screen}

Finally, to test the LCD screen, several test messages can be displayed on screen and visually inspected for
correctness as a sanity check.

\subsubsection{Database Integrity}

To test cloud database integrity, we can perform several test and security checks.

\textbf{Insecure Access}

To test the security of the cloud database, we can attempt to perform read and write operations using an incorrect API
key and ensure that the requests are denied.

\textbf{Stress Test}

To stress test the cloud database, several instances of the sensor data collection program can be run on multiple
Raspberry Pis, all of which will upload sensor data to the database. The database should:

\begin{itemize}
    \item Keep up with all of the simultaneous requests.
    \item Avoid any overwriting/race conditions with concurrent write operations.
\end{itemize}

\subsubsection{Software}

All software unit tests will be written using Pytest to get code coverage reports and automatic test running features.

\textbf{Smoke Detection System}

Logic for checking if sensor data is above a configured threshold will be tested in scenarios where:

\begin{itemize}
    \item The data is \textit{above} the configured threshold.
    \item The data is \textit{below} the configured threshold.
\end{itemize}

This will ensure that the logic correctly reports emergencies when sensor data is above a threshold and does not report
an emergency when the data is below the threshold.

\textbf{Alarm System}

Unit tests can be performed by simulating the events that would cause the alarm state machine to transition states.
Additionally, all of the logic performed in the states is called through the \texttt{Context} object that is passed to
the states' event handler methods. A mock version of the \texttt{Context} object can be created which will run assert
statements to verify that the correct logic is being called at the right time.

\textbf{Notification System}

Unit tests written for this system will guarantee that classes shown in the class diagram are constructed properly.

\texttt{User} and \texttt{UserSettings} data will be constructed from JSON returned from the Firebase Database, so we
can attempt to construct them with fake JSON data to see that they are constructed properly. Invalid JSON will be tested
to fail construction with an exception.

\textbf{Haptic Alarm System}

Unit tests written for the haptic alarm system will take a similar approach to the alarm system, where the state
machine \texttt{Context} object is mocked to contain assert statements in place of methods for performing system
actions. The individual states can again have their event handling methods called directly by the test runner.

\textbf{Web UI}

The web UI is more difficult to test because much of its functionality has to do with visual display. However, the API
endpoints used by the UI could be tested by sending GET and POST requests programmatically and verifying that the
correct response is returned. This would involve verifying JSON response structure and contents.

\subsection{Final Demo}

For the final demo, we will need to demonstrate several key features of our system:

\begin{itemize}
    \item Real-time display of sensor data. \\

          This will require us to run the web UI while the smoke detection system is active, which will display the live data as
          it updates.

    \item Configurable emergency threshold in real-time. \\

          This will require changing the temperature threshold via the UI to a low value while the smoke detection system is
          running. The smoke detection system should receive the change in configuration and then sound an alarm because room
          temperature will be higher than the threshold.

    \item User configurable timeouts. \\

          To demonstrate this feature, a timeout should be set via the web UI while the alarm is sounding. FANS should detect the
          timeout being set and stop the alarm for the duration of the timeout. The alarm should immediately resume once the
          timeout is complete.

    \item Updating user contact information. \\

          To demonstrate this functionality, a new user should be added via the web UI. The cloud database and the local database
          of the notification system can be verified manually to contain the new user information.

    \item Emergency notification emails. \\

          To demonstrate this feature, one of the testers should be included as a user in the database table of contact
          information. When the system triggers an emergency (due to a temperature threshold being set below room temperature),
          the tester should verify that they received an email from FANS with the emergency message and a recent time stamp.

    \item Alarm sounding during an emergency. \\

          When the temperature threshold is set to be below room temperature, testers should verify that the alarm node sounds
          the buzzer and flashes its LEDs.

    \item Haptic alarm buzzing during an emergency. \\

          When the temperature threshold is set to be below room temperature, testers should verify that the haptic alarm buzzes.

\end{itemize}

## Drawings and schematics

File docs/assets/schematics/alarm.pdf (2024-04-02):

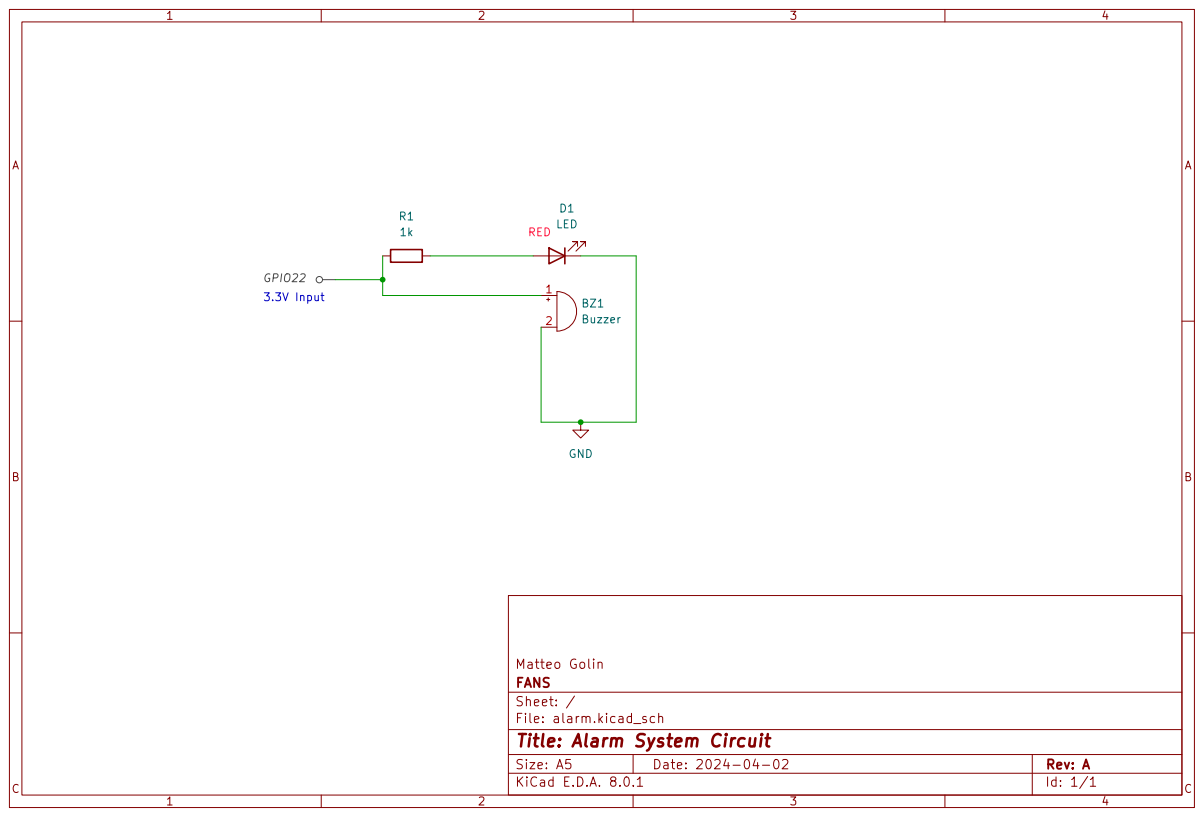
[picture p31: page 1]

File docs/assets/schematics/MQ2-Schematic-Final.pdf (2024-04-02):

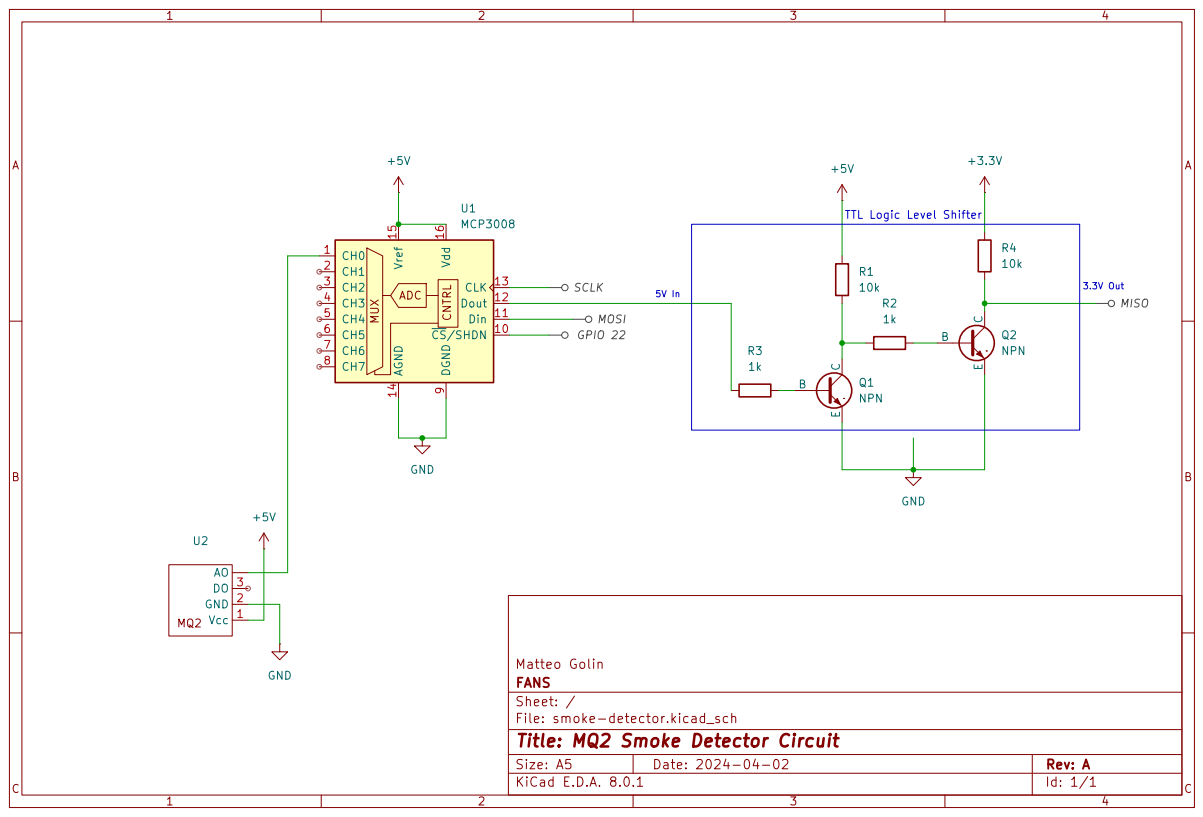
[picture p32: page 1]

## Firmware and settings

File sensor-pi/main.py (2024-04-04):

"""
Contains the main code for controlling the sensor data collection system node
of FANS. Sensor data is constantly read in a separate thread while the main
thread periodically uploads the recorded data to Firebase, reads user settings,
checks for data above thresholds and sends UDP messages to other system nodes
when an emergency has been activated or deactivated.
"""

__author__ = "Matteo Golin"

from types import FrameType
from typing import Optional
from threading import Timer
from sense_hat import SenseHat
import pyrebase
from pyrebase.pyrebase import Database
import json
import datetime as dt
import netifaces as ni
from multiprocessing import Queue, Process, active_children
from signal import signal, SIGTERM
from smoke_sensor import SmokeSensor
import time
from messages import Messages, SystemNode
from settings import Thresholds

FIREBASE_CONFIG: str = "firebase_config.json"
TIMESTAMP_FORMAT: str = "%Y-%m-%dT%H:%M:%S+%f"
DEVICE_NAMES: list[str] = ["alarm", "notifier"]

# Smoke detector settings
SCLK: int = 11
MISO: int = 9
MOSI: int = 10
CHIP_SELECT: int = 22


def collect_data(temp: Queue, smoke: Queue) -> None:
    """Process for collecting data from sensors."""

    # Open Sense Hat
    sensehat = SenseHat()

    # Create smoke sensor instance
    smoke_detector = SmokeSensor(
        sclk=SCLK,
        miso=MISO,
        mosi=MOSI,
        chip_select=CHIP_SELECT,
    )

    while True:
        time.sleep(0.5)  # Don't burn through CPU

        # Fetch temperature data and time stamp
        temperature = sensehat.get_temperature()

        # Fetch smoke status
        smoke_ppm = smoke_detector.read_ppm()

        # Give timestamp for measurements
        # Remove . because Firebase doesn't allow it
        timestamp = dt.datetime.now().isoformat().replace(".", "+")
        temp.put((timestamp, temperature))  # Put data on shared queue
        smoke.put((timestamp, smoke_ppm))


def get_latest_timeout(
    current_timeout: Optional[dt.datetime],
    db: Database,
) -> tuple[bool, dt.datetime, int]:
    """
    Returns the latest configured timeout from the database and a boolean which
    describes whether or not the timeout has changed in comparison to the
    currently active one.
    """
    data = db.child("timeout").order_by_key().limit_to_last(1).get().val()
    latest_timeout_timestamp = list(data.keys())[0]  # type: ignore
    duration = list(data.values())[0]  # type: ignore
    latest_timeout = dt.datetime.strptime(
        latest_timeout_timestamp,
        TIMESTAMP_FORMAT,
    )

    if current_timeout is not None:
        timeout_changed = latest_timeout > current_timeout
    else:
        timeout_changed = True

    return (timeout_changed, latest_timeout, duration)


def shutdown(sig: int, frame: FrameType) -> None:
    """Kills all child processes before terminating."""
    for child in active_children():
        child.terminate()
        exit(0)


def main() -> None:
    """Runs the primary logic of the sensor data fetcher."""

    # Connect using configuration
    with open(FIREBASE_CONFIG, "r") as file:
        config = json.loads(file.read())
    firebase = pyrebase.initialize_app(config)
    db = firebase.database()

    # Send current IP address for LAN communication between nodes
    ip_addr = ni.ifaddresses("wlan0")[ni.AF_INET][0]["addr"]
    db.child("devices").child("sensor-pi").set(ip_addr)

    # Check for configured thresholds
    thresholds = Thresholds.from_db(db)

    db.child("emergency").set(False)  # Start with emergency disabled

    # Get the latest timeout configuration to start the timeout
    _, current_timeout, _ = get_latest_timeout(None, db)
    current_timer: Timer = Timer(1, thresholds.update)

    # Get IP addresses of other device nodes
    devices = [SystemNode.from_db_device(name, db) for name in DEVICE_NAMES]

    # Track if an emergency has been triggered locally. This will allow
    # comparison with the database for turning off emergencies
    local_emergency = False

    # Handle shutdown signal
    signal(SIGTERM, shutdown)  # type: ignore

    # Start data collection with message queues
    temp = Queue()
    smoke = Queue()
    data_collection = Process(target=collect_data, args=(temp, smoke))
    data_collection.start()

    while True:
        # Get latest measurement
        timestamp, temperature = temp.get()
        timestamp, smoke_ppm = smoke.get()

        # Alert of emergency if threshold is exceeded or if there is smoke
        if thresholds.temperature_exceeded(
            temperature
        ) or thresholds.smoke_exceeded(smoke_ppm):
            db.child("emergency").set(True)
            local_emergency = True
            for device in devices:
                device.send_message(Messages.EMERGENCY)

        # Write measurement to database
        db.child("sensordata").child("temperature").child(timestamp).set(
            temperature
        )
        db.child("sensordata").child("smoke").child(timestamp).set(smoke_ppm)

        # Update configuration unless there's a timeout
        if not current_timer.is_alive():
            thresholds.update(db)

        # Check for timeout
        timeout_changed, current_timeout, duration = get_latest_timeout(
            current_timeout, db
        )

        if timeout_changed:
            # If a timer is already running, stop it
            if current_timer.is_alive():
                current_timer.cancel()

            time_expired = dt.datetime.now() - current_timeout
            actual_duration = duration - int(time_expired.total_seconds())

            # Make sure timer is not too old to be relevant
            if actual_duration > 0:
                current_timer = Timer(
                    actual_duration,
                    lambda: thresholds.update(db),
                )

                # Make thresholds so high that nothing will happen
                thresholds.max_out()
                current_timer.start()  # Start timer

        # Check for differing emergency status in database (user deactivated)
        if local_emergency and not db.child("emergency").get().val():
            local_emergency = False

            # Notify other nodes that emergency is over
            for device in devices:
                device.send_message(Messages.NO_EMERGENCY)


if __name__ == "__main__":
    main()

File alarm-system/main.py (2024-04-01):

"""
This is the main file of the alarm system which controls its behaviour. It
instantiates the alarm system finite state machine and starts it in motion,
while another thread waits for UDP events sent over the local network.
"""

from states import AlarmFSM
import netifaces as ni
import pyrebase
import json
import socket
from messages import Messages
from gpiozero import TonalBuzzer
from multiprocessing import Process, active_children
from types import FrameType
import warnings

FIREBASE_CONFIG: str = "./firebase_config.json"
UDP_RECEIVE_PORT: int = 2003
BUZZER_PIN: int = 22
UDP_BUFFER_SIZE: int = 100


def shutdown(sig: int, frame: FrameType) -> None:
    """Kills all child processes before terminating."""
    for child in active_children():
        child.terminate()
        exit(0)


def wait_for_message(channel: socket.socket) -> Messages:
    """Waits for a message over UDP."""
    data, _ = channel.recvfrom(UDP_BUFFER_SIZE)
    return Messages(int.from_bytes(data))


def main() -> None:
    # Suppress warnings
    warnings.simplefilter("ignore")

    # Connect using configuration
    with open(FIREBASE_CONFIG, "r") as file:
        config = json.loads(file.read())
    firebase = pyrebase.initialize_app(config)
    db = firebase.database()

    # Store current IP address for LAN communication between nodes
    ip_addr = ni.ifaddresses("wlan0")[ni.AF_INET][0]["addr"]
    db.child("devices").child("alarm").set(ip_addr)

    # Set up socket for UDP
    channel = socket.socket(socket.AF_INET, socket.SOCK_DGRAM)
    channel.bind((ip_addr, UDP_RECEIVE_PORT))

    # Set up thread for the state machine
    alarm_fsm = AlarmFSM(TonalBuzzer(BUZZER_PIN))
    alarm_system = Process(target=alarm_fsm.start)
    alarm_system.start()

    # In main thread, constantly wait for UDP communication and trigger the
    # correct event upon receipt
    while True:
        msg = wait_for_message(channel)

        # Forward the received message as an FSM event
        match msg:
            case Messages.EMERGENCY:
                alarm_fsm.emergency()
            case Messages.EMERGENCY_OVER:
                alarm_fsm.emergency_over()


if __name__ == "__main__":
    main()

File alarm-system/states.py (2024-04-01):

"""
This file contains the class definitions for the alarm system's finite state
machine. It defines the interface that all states must implement for handling
events, as well as the interface that the state machine context must implement
(for mocking during testing).

All states and the state machine context are defined here.
"""

from __future__ import annotations
from abc import ABC, abstractmethod
from threading import Timer
from typing import Protocol
from gpiozero import TonalBuzzer
from gpiozero.tones import Tone

B_FLAT: Tone = Tone.from_frequency(466.164)
TOGGLE_DURATION: int = 1  # In seconds


class Context(Protocol):
    """Defines the interface for the context required for the AlarmFSM."""

    state: State

    def emergency(self) -> None:
        """Handles the event of an emergency."""
        ...

    def emergency_over(self) -> None:
        """Handles the event of an emergency ending."""
        ...

    def timeout(self) -> None:
        """Handles the event of a timeout."""
        ...

    def start(self) -> None:
        """Starts the FSM."""
        ...

    def set_alarm_state(self, state: bool) -> None:
        """
        Turns on or off the alarm buzzer.
        Args:
            state: True for on, False for off.
        """
        ...

    def set_timeout(self, n: int) -> None:
        """
        Will trigger a timeout event in `n` seconds, applied to the context's
        current state.
        """
        ...


class AlarmFSM:
    """Represents the state machine context for the alarm state machine."""

    def __init__(self, buzzer: TonalBuzzer) -> None:
        self.buzzer: TonalBuzzer = buzzer
        # Start by waiting for an emergency
        self.__state: State = WaitForEmergency()

    @property
    def state(self) -> State:
        """Gets the state attribute."""
        return self.__state

    @state.setter
    def state(self, new_state: State) -> None:
        """
        Sets the state attribute after exiting the previous state, and then
        enters the next state.
        """
        self.__state.exit(self)  # type: ignore
        self.__state = new_state
        self.__state.entry(self)  # type: ignore

    def emergency(self) -> None:
        """Handles the event of an emergency."""
        self.__state.emergency(self)  # type: ignore

    def emergency_over(self) -> None:
        """Handles the event of an emergency ending."""
        self.__state.emergency_over(self)  # type: ignore

    def timeout(self) -> None:
        """Handles the event of a timeout."""
        self.__state.timeout(self)  # type: ignore

    def start(self) -> None:
        """Starts the FSM."""
        self.__state.entry(self)  # type: ignore

    def set_alarm_state(self, state: bool) -> None:
        """
        Turns on or off the alarm buzzer in sync with the LEDS.
        Args:
            state: True for on, False for off.
        """
        if state:
            self.buzzer.play(B_FLAT)
        else:
            self.buzzer.stop()

    def set_timeout(self, n: int) -> None:
        """
        Will trigger a timeout event in `n` seconds, applied to the context's
        current state.
        """
        Timer(n, self.timeout).start()


class State(ABC):
    """
    Represents the interface that all states must implement to handle incoming
    events.
    """

    @abstractmethod
    def emergency(self, context: Context) -> None:
        """Handles the event of an emergency."""

    @abstractmethod
    def emergency_over(self, context: Context) -> None:
        """Handles the event of an emergency ending."""

    @abstractmethod
    def timeout(self, context: Context) -> None:
        """Handles a timer event."""

    def entry(self, context: Context) -> None:
        """Performs the entry activity of the state."""
        return

    def exit(self, context: Context) -> None:
        """Performs the exit activity of the state."""
        return


class WaitForEmergency(State):
    """Represents the state where the alarm is waiting for an emergency."""

    def entry(self, context: Context) -> None:
        """Performs the entry activity for this state."""
        return

    def emergency(self, context: Context) -> None:
        """Handles the event of an emergency."""
        context.state = AlarmOn()

    def emergency_over(self, context: Context) -> None:
        """
        Handles the event of the emergency ending. In this case, do nothing
        except wait again.
        """
        return

    def timeout(self, context: Context) -> None:
        """Handles the event of a timeout event."""
        return


class AlarmOn(State):
    """Represents the state where the alarm has its buzzer and LED on."""

    def entry(self, context: Context) -> None:
        context.set_alarm_state(True)
        context.set_timeout(TOGGLE_DURATION)

    def emergency(self, context: Context) -> None:
        """Handles the event of an emergency."""
        return

    def emergency_over(self, context: Context) -> None:
        """Handles the event of the emergency ending."""
        context.set_alarm_state(False)
        context.state = WaitForEmergency()

    def timeout(self, context: Context) -> None:
        """Handles the event of a timeout event."""
        context.state = AlarmOff()


class AlarmOff(State):
    """Represents the state where the alarm has its buzzer and LED off."""

    def entry(self, context: Context) -> None:
        context.set_alarm_state(False)
        context.set_timeout(TOGGLE_DURATION)

    def emergency(self, context: Context) -> None:
        """Handles the event of an emergency."""
        return

    def emergency_over(self, context: Context) -> None:
        """Handles the event of the emergency ending."""
        context.state = WaitForEmergency()

    def timeout(self, context: Context) -> None:
        """Handles the event of a timeout event."""
        context.state = AlarmOn()

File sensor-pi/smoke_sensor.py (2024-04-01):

"""
This file contains a helper class for controlling and reading the MQ2 smoke
sensor over the serial peripheral interface (SPI) protocol with the MCP3008
analog-to-digital converter.
"""

import busio
import digitalio
import adafruit_mcp3xxx.mcp3008 as MCP
from adafruit_mcp3xxx.analog_in import AnalogIn

NO_PPM_VOLTAGE: float = 0.48
MAX_PPM: float = 10000


class SmokeSensor:
    """
    Represents the Flying-Fish MQ2 smoke sensor connected to the Raspberry Pi
    SPI interface through the MCP3008 ADC.
    """

    def __init__(
        self, sclk: int, miso: int, mosi: int, chip_select: int
    ) -> None:
        self.spi = busio.SPI(clock=sclk, MISO=miso, MOSI=mosi)
        self.cs = digitalio.DigitalInOut(digitalio.Pin(chip_select))
        self.mcp = MCP.MCP3008(self.spi, self.cs)
        self.channel = AnalogIn(self.mcp, MCP.P0)

    def read_voltage(self) -> float:
        """Reads the voltage output by the smoke sensor."""
        return self.channel.voltage

    def read_ppm(self) -> float:
        """Returns the estimated amount of smoke in the air in PPM."""
        slope = MAX_PPM / (self.mcp.reference_voltage - NO_PPM_VOLTAGE)
        return slope * (self.read_voltage() - NO_PPM_VOLTAGE)

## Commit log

2024-02-12 docs: added sequence diagram for alarm triggering use case
2024-02-12 docs: added use case for updating contact information
2024-02-12 docs: added use case for changing emergency trigger threshold
2024-02-13 docs: fixed smoke detection use case image and commented out missing image for now
2024-02-29 feat: time series temperature data is now stored in a firebase real-time db.
2024-02-29 feat: read temperature threshold configuration on startup and trigger emergency if temperature measurement exceeds the threshold.
2024-02-29 fix: Correct settings page route
    [main.py]
2024-03-07 feat: completed firebase sensor data fetching proof of concept. no fancy display, simply printing time series data as JSON to prove there is communication.
2024-03-07 feat: created a mock program for the Pi Pico haptic alarm that buzzes as long as an emergency is active in the database.
    [main.py]
2024-03-07 bug: fixed typo and ignore pycache files
    [states.py]
2024-03-07 feat: created the udp communication between the alarm and the sensor collection program
2024-03-07 feat: sensor collection program sends emergency notifications to the alarm system
2024-03-07 feat:final changes on the buzzer
    [haptic_alarm.py]
2024-03-11 Mentioned I2C just in case.
2024-03-14 docs: inserted schematics of buzzer with Pico
2024-03-14 chore: list the requirements for the sensor data collection system
2024-03-14 feat: added unit tests for temperature
2024-03-14 refactor: Switch the content of index.html and temp-index.html
2024-03-14 feat: update FSM to have getter and setter for state that can run entry logic on state switches
2024-03-14 chore: remove debug print
2024-03-18 feat: implemented interfacing of state machine with active buzzer to play alarm sound.
    [main.py, states.py]
2024-03-20 feat: Add test case that checks that the values from the firebase db are being displayed in the web gui
2024-03-20 feat: Add code for using the buzzer with a pico w
    [pico_haptic_alarm.py]
2024-03-21 feat: added test file for buzzing alarm
    [test_alarm.py]
2024-03-21 feat: sensor data collection is multithreaded
2024-03-21 chore: remove print statement for debug
2024-03-26 Fixed flake8 line length warnings.
    [states.py]
2024-03-27 feat: added support for detecting smoke from the MQ2 gas sensor connected to GPIO pin 22.
2024-03-28 Interfaced with the MQ2 smoke sensor using the SPI interface. Smoke measurements are now integrated into the system.
2024-03-29 feat: Add UNFINISHED code for working with the pico w
2024-03-29 Updated home page to include latest smoke and temperature data.
2024-03-29 bug: pyrebase requests do not read entire db now.
    [main.py]
2024-03-29 feat: updated home page to include latest smoke and temperature data.
2024-03-29 feat: smoke and temperature graphs are now displayed and refresh every 3 seconds.
2024-03-29 feat: most of the timer logic is in place, but it needs to be tested on the Pi
2024-03-29 feat: Update pico alarm system logic (button logic not working properly)
    [pico_haptic_alarm.py]
2024-03-29 bug: stopped timers that are too old from being set
    [main.py]
2024-03-29 chore: fixed button colors
2024-03-29 feat: Update logic for button
2024-03-29 bug: hacky fix for setting globals
    [main.py]
2024-04-01 chore: fixed flake8 warnings in alarm system by hand.
    [main.py, messages.py, test_alarm.py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]
2024-04-01 bug: fixed problem where parameter was not passed to update function
    [main.py]
2024-04-01 chore: remove debug prints
2024-04-01 chore: fix linting errors.
    [main.py, messages.py, settings.py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]
2024-04-02 docs: created smoke detection circuit in KiCad
    [smoke-detector.kicad_pcb, smoke-detector.kicad_sch]
2024-04-02 docs: added alarm system schematic
    [alarm.kicad_pcb, alarm.kicad_sch]
2024-04-02 bug: fixed erroneous smoke check
    [main.py, settings.py]
2024-04-02 bug: message not encoded properly
    [messages.py]
2024-04-02 docs: added installation instructions for the sensor and alarm nodes.
2024-04-03 docs: added pico fritzing image
2024-04-03 chore: move up schematic to hardware sections
2024-04-03 feat: implemented updating current temperature and smoke values.
2024-04-04 chore: fix linting errors in web-app.
    [main.py]
2024-04-04 feat: fixed flake8 errors for pico_haptic_alarm.py
    [pico_haptic_alarm.py]
2024-04-04 feat: resolved flake8 issues
    [messages.py]
2024-04-04 featL fixed flake8 for haptic_alarm_test.py
    [haptic_alarm_test.py]
2024-04-04 feat: fixed flake8 for pico_web_server.py
    [pico_web_server.py]
2024-04-05 chore: fix last linting and formatting issues
    [pico_haptic_alarm.py]
2024-04-09 docs: Moved one of the sequence diagrams to appendix and tried to cut down on text.
